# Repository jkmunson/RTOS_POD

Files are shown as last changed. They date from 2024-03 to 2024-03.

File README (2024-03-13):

BEGINNING OF NOTES BY WYATT:
3/10/2024

* TFT display guide: https://www.youtube.com/watch?v=3qnB5gsp8eE&t=2s
* SD card guide: https://01001000.xyz/2020-08-09-Tutorial-STM32CubeIDE-SD-card/
* All the SPI and GPIO pin assignments are made in the .ioc file.
* SCK, MISO, and MOSI are automaticly assigned by the SPI enabled in the .ioc
* ^ but CS, RESET, and DC need to be assigned manually.
* The ili9341.h file and main.h file will need to reflect the .ioc file pin assignments. 
* I used stack size = 512 for the display/SD thread. Testing lower values has caused a fault in the past.
* Will need to change the "startup file" from f4xxxx to whichever board we are using.
* None of the display's touch screen pins are used (i.e. T_IRQ1, T_DO, T_DIN, T_CS, T_CLK)

I was on an f4xxx board, but I used the following SPI/GPIOs for the SD/Display:
SD:
	SCK		->	PB10
	MISO	->	PC2
	MOSI	->	PC1
	CS		->	PC3
DISPLAY:
	SD0 (MISO)	->	n/a (specify master only transmit in .ioc)
	LED			->	+3.3V
	SCK			->	PA5
	SDI	(MOSI)	->	PA7
	DC			->	PB1
	RESET		->	PB0
	CS			->	PA4
	VCC			->  +5V
	
I uploaded my wyatt.c and wyatt.h code, but it doesn't look like main.c is configured for FreeRTOS to run.
Once it is, ADD THE FOLLOWING CODE AS ITS OWN THREAD:
  
*   HOW THE FSM WORKS:
	The display initializes by showing the names of the files on the SD card, and blinking to show which file is currently hovered over.
	Change boolean variables "sel_next" and "sel_prev" to highlight files other than the one currently highlighted.
	change boolean variable "readFile" to open the file that's currently hovered over and access its contents.
	change boolean variable "viewDirectory" to close the file you're reading and view the list of file names again.
	
	changing "readFile" while already reading a file does nothing.
	changing "viewDirectory" while already viewing the directory does nothing.
	
END OF NOTES BY WYATT.

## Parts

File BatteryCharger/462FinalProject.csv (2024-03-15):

Source: | /home/jkmunson/workspace/win24/RTOS_POD/BatteryCharger/462FinalProject.kicad_sch
Date: | Fri 15 Mar 2024 08:57:17 AM PDT
Tool: | Eeschema 7.0.10
Generator: | /app/share/kicad/plugins/bom_csv_grouped_by_value_with_fp.py
Component Count: | 46
Ref | Qnty | Value | Cmp name | Footprint | Description | Vendor | DNP
C1, C2, C3, C5, C6 | 5 | 10u | C_Small | Capacitor_SMD:C_0805_2012Metric_Pad1.18x1.45mm_HandSolder | Unpolarized capacitor, small symbol
C4 | 1 | .1u | C_Small | Capacitor_SMD:C_0805_2012Metric_Pad1.18x1.45mm_HandSolder | Unpolarized capacitor, small symbol
D1, D5, D6, D7 | 4 | MBR0530 | 1N5711 | Diode_SMD:D_SOD-123 | 70V 33mA Schottky diode, DO-35
IC1 | 1 | TPS562231DRLR | TPS562231DRLR | Library:SOTFL50P160X60-6N | 4.5-V to 17-V input, 2-A output, synchronous step-down converter
J2 | 1 | 3_Pin_Header_to_Battery | Conn_01x03_Pin | Connector_PinHeader_2.54mm:PinHeader_1x03_P2.54mm_Vertical | Generic connector, single row, 01x03, script generated
J3 | 1 | USB_B_Micro | USB_B_Micro | Library:USB_Micro-B_roundholes | USB Micro Type B connector
J4 | 1 | 3_Pin_Header_to_IPOD | Conn_01x03_Pin | Connector_PinHeader_2.54mm:PinHeader_1x03_P2.54mm_Vertical | Generic connector, single row, 01x03, script generated
J5 | 1 | Conn_01x04_Pin | Conn_01x04_Pin | Connector_PinHeader_2.54mm:PinHeader_1x04_P2.54mm_Vertical | Generic connector, single row, 01x04, script generated
L1 | 1 | SRR1205-500YL | SRR1205-500YL | Library:SRR1205500YL | Fixed Inductors 50uH 15% SMD 1205
L2 | 1 | 3.3u | L | Library:CC322522A-4R7K | Inductor
Q1, Q2 | 2 | MMFTN6001 | Q_NMOS_GSD | Package_TO_SOT_SMD:SOT-23 | N-MOSFET transistor, gate/source/drain
Q3, Q4, Q9 | 3 | SI2302 | Q_NMOS_GSD | Package_TO_SOT_SMD:SOT-23 | N-MOSFET transistor, gate/source/drain
Q6, Q7, Q8 | 3 | BSS84AK,215 | BSS84AK,215 | Library:SOT95P230X110-3N | BSS84AK,215 P-Channel MOSFET, 180 mA, 50 V, 3-Pin SOT-23 Nexperia
R1 | 1 | 100m | R | Resistor_SMD:R_0805_2012Metric | Resistor
R4, R10, R12 | 3 | 1k | R | Resistor_SMD:R_0805_2012Metric | Resistor
R5 | 1 | 45.3k | R | Library:CR0603-FX-4532ELF | Resistor
R9 | 1 | 100k | R | Resistor_SMD:R_0805_2012Metric | Resistor
RN1, RN2 | 2 | R_Pack04_Split_2 | R_Pack04_Split | Resistor_SMD:R_Array_Concave_4x0603 | 4 resistor network, parallel topology, split
TP1, TP2, TP3, TP4, TP5, TP6, TP7, TP8, TP9, TP10 | 10 | TestPoint | TestPoint | TestPoint:TestPoint_Loop_D2.50mm_Drill1.85mm | test point
U1 | 1 | MIC5504-3.3YM5 | MIC5504-3.3YM5 | Package_TO_SOT_SMD:SOT-23-5 | 300mA Low-dropout Voltage Regulator, Vout 3.3V, Vin up to 5.5V, SOT-23
U2 | 1 | STM32G030F6Px | STM32G030F6Px | Package_SO:TSSOP-20_4.4x6.5mm_P0.65mm | STMicroelectronics Arm Cortex-M0+ MCU, 32KB flash, 8KB RAM, 64 MHz, 2.0-3.6V, 17 GPIO, TSSOP20
U3 | 1 | ~ | MCP6489-E/SL | Package_SO:SOIC-14_3.9x8.7mm_P1.27mm

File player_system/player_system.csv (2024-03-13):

Component Count: |  | 190
Ref | Ordered? | Qnty | Value | Cmp name | Footprint | Description | Vendor | DNP
BIASTRIM1 | Y | 1 | 5k | R_Potentiometer_Trim | Potentiometer_THT:Potentiometer_ACP_CA9-H5_Horizontal | Trim-potentiometer
C1, C2 | Y | 2 | 10pf C0G 2% | C_Small | Capacitor_SMD:C_0805_2012Metric_Pad1.18x1.45mm_HandSolder | Unpolarized capacitor, small symbol
C3, C4, C5, C6 | Y | 4 | 100n | C_Small | Capacitor_SMD:C_0805_2012Metric_Pad1.18x1.45mm_HandSolder | Unpolarized capacitor, small symbol
C7, C8, C9, C10, C11, C12, C13, C14, C15, C16, C17, C18, C19, C20, C21, C22, C23, C24 | Y | 18 | 10uf | C_Small | Capacitor_SMD:C_0805_2012Metric_Pad1.18x1.45mm_HandSolder | Unpolarized capacitor, small symbol
C25 | Y | 1 | 10u | C_Small | Resistor_SMD:R_0805_2012Metric_Pad1.20x1.40mm_HandSolder | Unpolarized capacitor, small symbol
GAINTRIM1, GAINTRIM2 | Y | 2 | 10k | R_Potentiometer_Trim | Potentiometer_THT:Potentiometer_ACP_CA9-H5_Horizontal | Trim-potentiometer
J1 | Y | 1 | ~ | Conn_01x02_Pin | Connector_PinHeader_2.54mm:PinHeader_1x02_P2.54mm_Vertical | Generic connector, single row, 01x02, script generated
JTAG1 | Y | 1 | PGM | Conn_02x07_Odd_Even | Connector_PinHeader_1.27mm:PinHeader_2x07_P1.27mm_Vertical | Generic connector, double row, 02x07, odd/even pin numbering scheme (row 1 odd numbers, row 2 even numbers), script generated (kicad-library-utils/schlib/autogen/connector/)
NORFLASH1, NORFLASH2 | Y | 2 | ~ | IS25LP128F-JBLE-TR | Package_SO:SOP-8_5.28x5.23mm_P1.27mm
PWR_IN1 | Y | 1 | ~ | Conn_01x03_Pin_1 | Connector_PinHeader_2.54mm:PinHeader_1x03_P2.54mm_Vertical | Generic connector, single row, 01x03, script generated
Q1, Q2, Q3, Q4, Q5, Q6, Q7, Q8 | Y | 8 | SI2302 | Q_NMOS_GSD | Package_TO_SOT_SMD:SOT-23 | N-MOSFET transistor, gate/source/drain
R1, R2 | Y | 2 | 1k | R_Small | Resistor_SMD:R_0805_2012Metric_Pad1.20x1.40mm_HandSolder | Resistor, small symbol
RESET1 | Y | 1 | RESET | SW_Push | Button_Switch_SMD:SW_SPST_EVPBF | Push button switch, generic, two pins
RN1, RN2 | Y | 2 | 1M-1% | R_Pack04_Split | Resistor_SMD:R_Array_Convex_4x1206 | 4 resistor network, parallel topology, split
RN3, RN4, RN5, RN6, RN7 | Y | 5 | 10k | R_Pack04_Split | Resistor_SMD:R_Array_Concave_4x0603 | 4 resistor network, parallel topology, split
ROTARY1 | Y | 1 | ~ | RotaryEncoder_Switch | Rotary_Encoder:RotaryEncoder_Alps_EC11E-Switch_Vertical_H20mm_CircularMountingHoles | Rotary encoder, dual channel, incremental quadrate outputs, with switch
SD_DAT1, SD_DAT2 | Y | 2 | . | Conn_01x01_Socket | rtospod_footprints:tht_testpt | Generic connector, single row, 01x01, script generated
SDCARD1 | Y | 1 | ~ | Micro_SD_Card | rtospod_footprints:J_SD_Card-micro_socket_A | Micro SD Card Socket
SW1, SW2, SW3, SW4 | Y | 4 | ~ | SW_Push | Button_Switch_SMD:SW_SPST_EVPBF | Push button switch, generic, two pins
TFT1 | Y | 1 | ~ | PBC_ILI9341_2.8_TFT_SPI_240x320_V1.2 | rtospod_footprints:TFT_SPI_240X320
U1, U5 | Y | 2 | ~ | MCP6489-E/SL | Package_SO:SOIC-14_3.9x8.7mm_P1.27mm
U2 | Y | 1 | STM32G474VEHx | STM32G474VEHx | Package_BGA:TFBGA-100_8x8mm_Layout10x10_P0.8mm | STMicroelectronics Arm Cortex-M4 MCU, 512KB flash, 128KB RAM, 170 MHz, 1.71-3.6V, 86 GPIO, TFBGA100
U3 | Y | 1 | STM32G030F6Px | STM32G030F6Px | Package_SO:TSSOP-20_4.4x6.5mm_P0.65mm | STMicroelectronics Arm Cortex-M0+ MCU, 32KB flash, 8KB RAM, 64 MHz, 2.0-3.6V, 17 GPIO, TSSOP20
U4 | Y | 1 | LDI1117-05H | AP1117-15 | Package_TO_SOT_SMD:SOT-223-3_TabPin2 | 1A Low Dropout regulator, positive, 1.5V fixed output, SOT-223
VOLUME1 | Y | 1 | 5k | R_Potentiometer | rtospod_footprints:CIRCULAR_POT | Potentiometer
Y1 | Y | 1 | 16mhz 10ppm | Crystal_Small | Crystal:Crystal_SMD_2520-4Pin_2.5x2.0mm | Two pin crystal, small symbol
Reference |  | Qty | Value | Footprint | DNP | Manufacturer Part Number | Mouser Price/Stock
C1, C2, C3, C5, C6 | Y | 5 | 10u | Capacitor_SMD:C_0805_2012Metric_Pad1.18x1.45mm_HandSolder |  | CL21A106KOQNNNE | https://www.mouser.com/ProductDetail/Samsung-Electro-Mechanics/CL21A106KOQNNNE
C4 | Y | 1 | .1u | Capacitor_SMD:C_0805_2012Metric_Pad1.18x1.45mm_HandSolder |  | MSAST105SB5104KFNA01 | https://www.mouser.com/ProductDetail/TAIYO-YUDEN/MSAST105SB5104KFNA01
D1, D5, D6, D7 | Y | 4 | MBR0530 | Diode_SMD:D_SOD-123 |  | MBR0530 | https://www.mouser.com/ProductDetail/Micro-Commercial-Components-MCC/MBR0530-TP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
IC1 | Y | 1 | TPS562231DRLR | Library:SOTFL50P160X60-6N |  | TPS562231DRLR | https://www.mouser.co.uk/ProductDetail/Texas-Instruments/TPS562231DRLR?qs=l4Gc20tDgJK5KnXgCyg0Bw%3D%3D
J2 | Y | 1 | 3_Pin_Header_to_Battery | Connector_PinHeader_2.54mm:PinHeader_1x03_P2.54mm_Vertical
J3 | Y | 1 | USB_B_Micro | Library:USB_Micro-B_roundholes
J4 | Y | 1 | 3_Pin_Header_to_IPOD | Connector_PinHeader_2.54mm:PinHeader_1x03_P2.54mm_Vertical
J5 | Y | 1 | Conn_01x04_Pin | Connector_PinHeader_2.54mm:PinHeader_1x04_P2.54mm_Vertical
L1 | Y | 1 | SRR1205-500YL | Library:SRR1205500YL |  |  | https://www.mouser.co.uk/ProductDetail/Bourns/SRR1205-500YL?qs=iR9JlTGiDnVu0txHEBsynw%3D%3D
L2 | Y | 1 | 3.3u | Library:CC322522A-4R7K |  | CC322522A-4R7K | https://www.mouser.com/ProductDetail/Bourns/CC322522A-4R7K?qs=BJlw7L4Cy7%2Fy09%2BRq8LovQ%3D%3D
Q1, Q2 | Y | 2 | MMFTN6001 | Package_TO_SOT_SMD:SOT-23 |  | MMFTN6001 | https://www.mouser.com/ProductDetail/Diotec-Semiconductor/MMFTN6001?qs=Wj%2FVkw3K%252BMBEABncUaRa2w%3D%3D
Q3, Q4, Q9 | Y | 3 | SI2302 | Package_TO_SOT_SMD:SOT-23 |  | SI2302 | https://www.mouser.com/ProductDetail/Micro-Commercial-Components-MCC/SI2302?qs=6W4OQKoqJ0s%2FjuQxID9btg%3D%3D
Q6, Q7, Q8 | Y | 3 | BSS84AK,215 | Library:SOT95P230X110-3N |  | BSS84AK,215 | https://www.mouser.co.uk/ProductDetail/Nexperia/BSS84AK215?qs=A1cBxND5mHJndJgHJTE1yg%3D%3D
R1 | Y | 1 | 100m | Resistor_SMD:R_0805_2012Metric |  | 73L3R10J | https://www.mouser.com/ProductDetail/CTS-Electronic-Components/73L3R10J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
R4, R10, R12 | Y | 3 | 1k | Resistor_SMD:R_0805_2012Metric |  | CR0805-JW-102ELF | https://www.mouser.com/ProductDetail/Bourns/CR0805-JW-102ELF?qs=sGAEpiMZZMtlubZbdhIBIPJRFm2x4gVbKRFwRkY2vaI%3D
R5 | Y | 1 | 45.3k | Library:CR0603-FX-4532ELF |  | RC0805FR-0745K3L | https://www.mouser.com/ProductDetail/YAGEO/RC0805FR-0745K3L
R9 | Y | 1 | 100k | Resistor_SMD:R_0805_2012Metric |  | RC0805JR-10100KL | https://www.mouser.com/ProductDetail/YAGEO/RC0805JR-10100KL
RN1, RN2 | Y | 2 | R_Pack04_Split_2 | Resistor_SMD:R_Array_Concave_4x0603
TP1, TP2, TP3, TP4, TP5, TP6, TP7, TP8, TP9, TP10 |  | 10 | TestPoint | TestPoint:TestPoint_Loop_D2.50mm_Drill1.85mm
U1 | Y | 1 | MIC5504-3.3YM5 | Package_TO_SOT_SMD:SOT-23-5
U2 | Y | 1 | STM32G030F6Px | Package_SO:TSSOP-20_4.4x6.5mm_P0.65mm
U3 |  | 1 | ~ | Package_SO:SOIC-14_3.9x8.7mm_P1.27mm

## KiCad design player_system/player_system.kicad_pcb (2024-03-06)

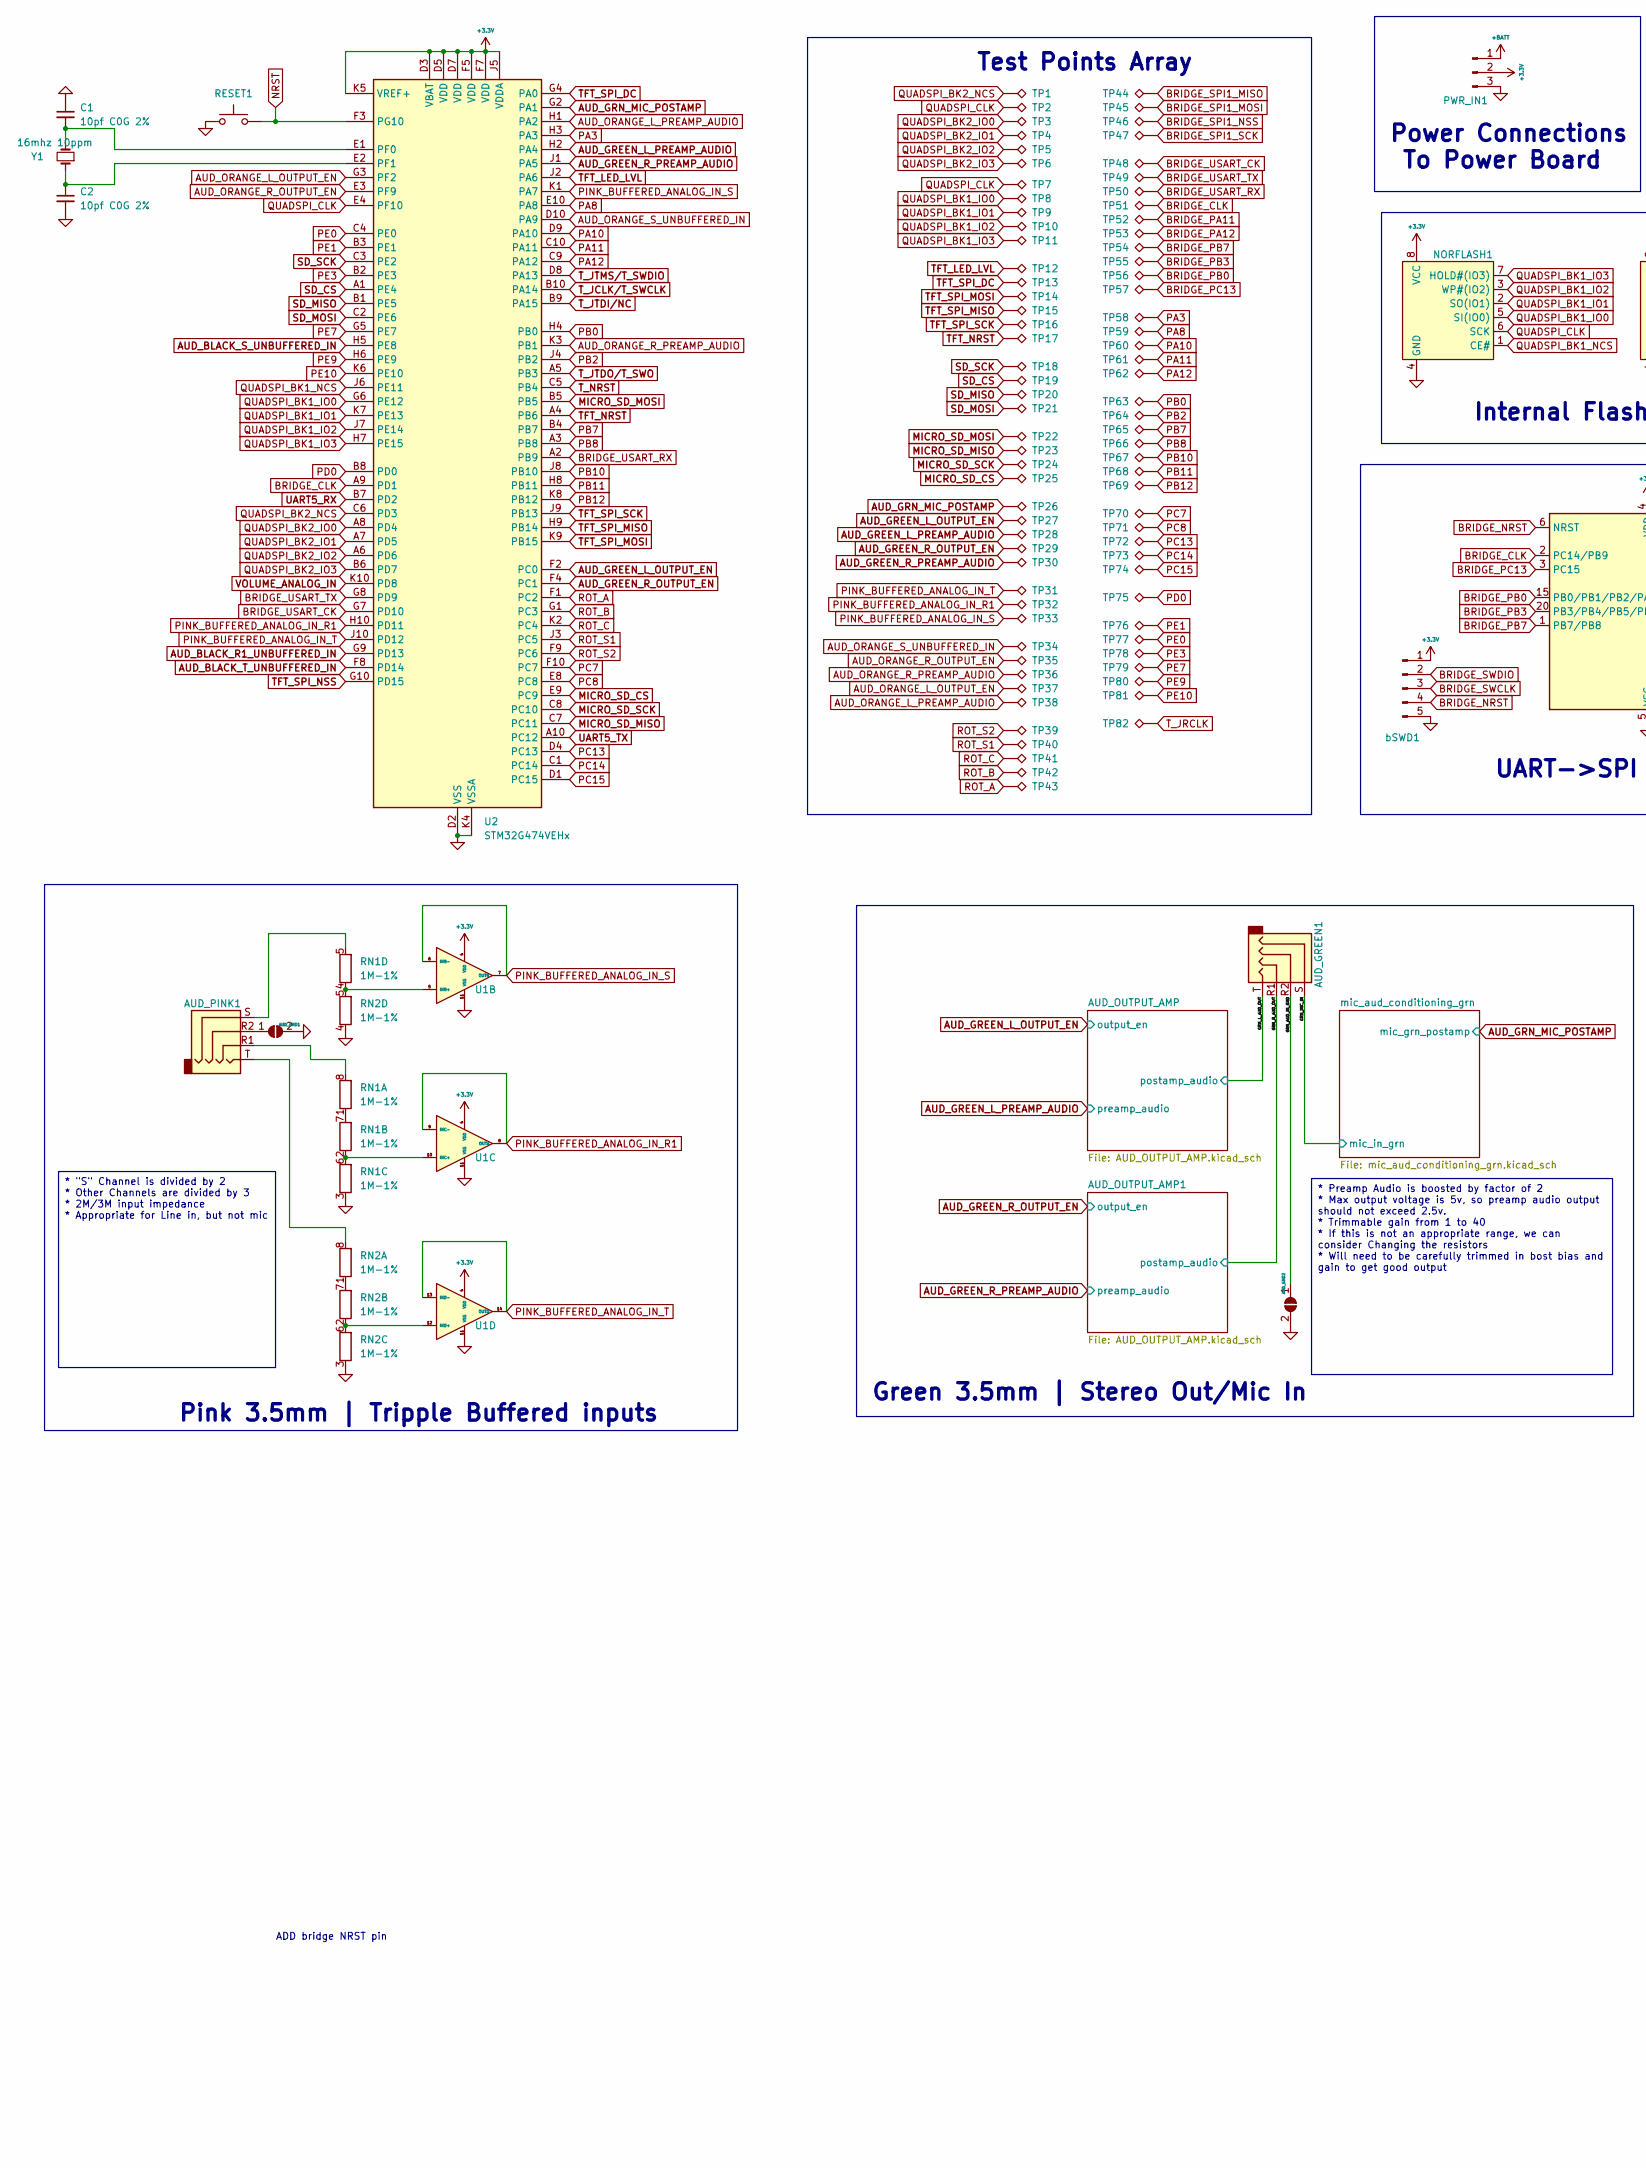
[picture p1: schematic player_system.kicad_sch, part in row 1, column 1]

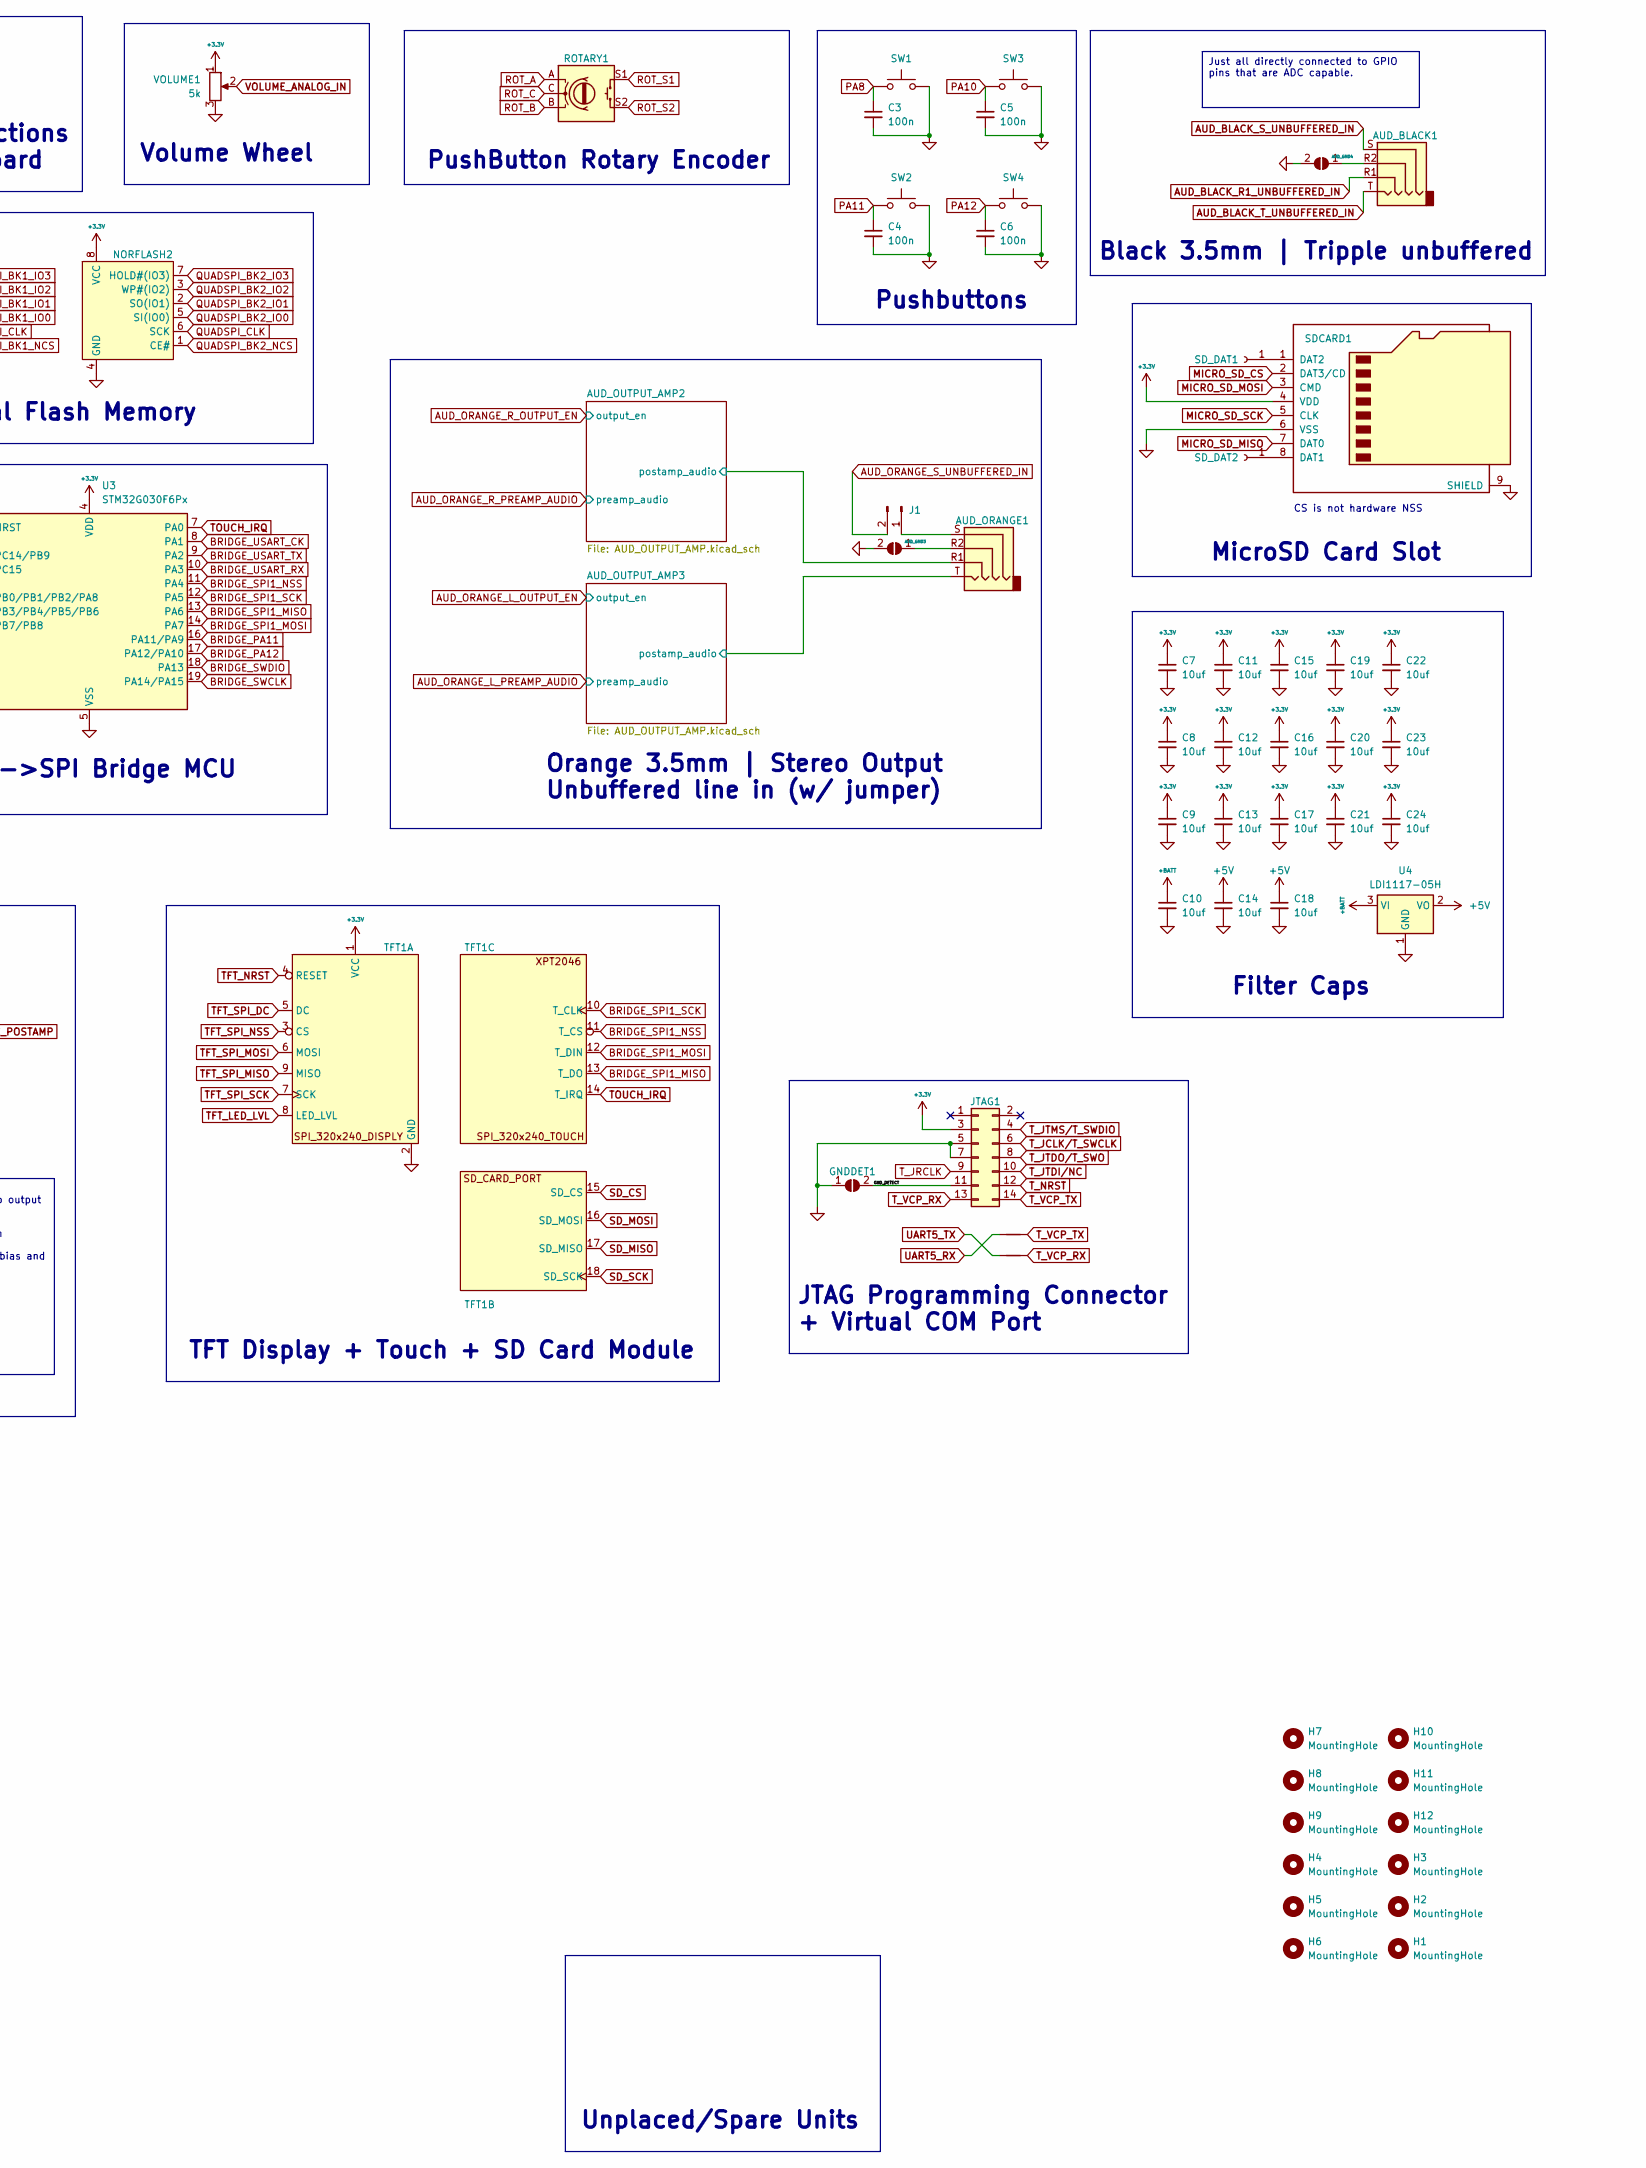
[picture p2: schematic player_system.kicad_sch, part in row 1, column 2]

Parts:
AUD_BLACK1: TRRS_JACK_3.5mm
AUD_GND1, AUD_GND2, AUD_GND3, AUD_GND4: SolderJumper_2_Open; SolderJumper-2_P1.3mm_Open_RoundedPad1.0x1.5mm
AUD_GREEN1: TRRS_JACK_3.5mm
AUD_ORANGE1: TRRS_JACK_3.5mm
AUD_PINK1: TRRS_JACK_3.5mm
C1, C2: 10pf C0G 2%; C_0805_2012Metric_Pad1.18x1.45mm_HandSolder
C3, C4, C5, C6: 100n; C_0805_2012Metric_Pad1.18x1.45mm_HandSolder
C7, C8, C9, C10, C11, C12, C13, C14, C15, C16, C17, C18, C19, C20, C21, C22, C23, C24: 10uf; C_0805_2012Metric_Pad1.18x1.45mm_HandSolder
GNDDET1: SolderJumper_2_Open; SolderJumper-2_P1.3mm_Open_RoundedPad1.0x1.5mm
H1, H2, H3, H4, H5, H6, H7, H8, H9, H10, H11, H12: MountingHole; MountingHole_2.2mm_M2
J1: PinHeader_1x02_P2.54mm_Vertical
JTAG1: PGM; PinHeader_2x07_P1.27mm_Vertical
NORFLASH1, NORFLASH2: SOP-8_5.28x5.23mm_P1.27mm
NT2, NT3: NetTie_2; NetTie-2_SMD_Pad0.5mm
PWR_IN1: PinHeader_1x03_P2.54mm_Vertical
RESET1: RESET; SW_SPST_EVPBF
RN1, RN2: 1M-1%; R_Array_Convex_4x1206
ROTARY1: RotaryEncoder_Alps_EC11E-Switch_Vertical_H20mm_CircularMoun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
SDCARD1: J_SD_Card-micro_socket_A
SD_DAT1, SD_DAT2: .; tht_testpt
SW1, SW2, SW3, SW4: SW_SPST_EVPBF
TFT1: TFT_SPI_240X320
TP1, TP2, TP3, TP4, TP5, TP6, TP7, TP8, TP9, TP10, TP11, TP12, TP13, TP14, TP15, TP16, TP17, TP18, TP19, TP20, TP21, TP22, TP23, TP24, TP25, TP26, TP27, TP28, TP29, TP30, TP31, TP32, TP33, TP34, TP35, TP36, TP37, TP38, TP39, TP40, TP41, TP42, TP43, TP44, TP45, TP46, TP47, TP48, TP49, TP50, TP51, TP52, TP53, TP54, TP55, TP56, TP57, TP58, TP59, TP60, TP61, TP62, TP63, TP64, TP65, TP66, TP67, TP68, TP69, TP70, TP71, TP72, TP73, TP74, TP75, TP76, TP77, TP78, TP79, TP80, TP81, TP82: tht_testpt
U1: SOIC-14_3.9x8.7mm_P1.27mm
U2: STM32G474VEHx; TFBGA-100_8x8mm_Layout10x10_P0.8mm
U3: STM32G030F6Px; TSSOP-20_4.4x6.5mm_P0.65mm
U4: LDI1117-05H; SOT-223-3_TabPin2
VOLUME1: 5k; CIRCULAR_POT
Y1: 16mhz 10ppm; Crystal_SMD_2520-4Pin_2.5x2.0mm
bSWD1: BRIDGE_SWD; PinHeader_1x05_P2.54mm_Vertical

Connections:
+3.3V: C7.1, C8.1, C9.1, C11.1, C12.1, C13.1, C15.1, C16.1, C17.1, C19.1, C20.1, C21.1, C22.1, C23.1, C24.1, JTAG1.3, NORFLASH1.8 (VCC), NORFLASH2.8 (VCC), PWR_IN1.2, SDCARD1.4 (VDD), TFT1.1 (VCC), U1.4 (VDD), U2.D3 (VBAT), U2.D5 (VDD), U2.D7 (VDD), U2.F5 (VDD), U2.F7 (VDD), U2.J5 (VDDA), U2.K5 (VREF+), U3.4 (VDD), VOLUME1.1, bSWD1.1; also elsewhere on the board
+5V: C14.1, C18.1, U4.2 (VO); also elsewhere on the board
+BATT: C10.1, PWR_IN1.1, U4.3 (VI); also elsewhere on the board
/AUD_OUTPUT_AMP2/postamp_audio: AUD_ORANGE1.R1; also elsewhere on the board
/AUD_OUTPUT_AMP3/postamp_audio: AUD_ORANGE1.T; also elsewhere on the board
/GND_DETECT: GNDDET1.2 (B), JTAG1.11
/GRN_AUD_IN_GND: AUD_GND2.1 (A), AUD_GREEN1.R2
/GRN_L_AUD_OUT: AUD_GREEN1.T; also elsewhere on the board
/GRN_MIC_IN: AUD_GREEN1.S; also elsewhere on the board
/GRN_R_AUD_OUT: AUD_GREEN1.R1; also elsewhere on the board
AUD_BLACK_R1_UNBUFFERED_IN: AUD_BLACK1.R1, U2.G9 (PD13)
AUD_BLACK_S_UNBUFFERED_IN: AUD_BLACK1.S, U2.H5 (PE8)
AUD_BLACK_T_UNBUFFERED_IN: AUD_BLACK1.T, U2.F8 (PD14)
AUD_GREEN_L_OUTPUT_EN: TP27.1, U2.F2 (PC0); also elsewhere on the board
AUD_GREEN_L_PREAMP_AUDIO: TP28.1, U2.H2 (PA4); also elsewhere on the board
AUD_GREEN_R_OUTPUT_EN: TP29.1, U2.F4 (PC1); also elsewhere on the board
AUD_GREEN_R_PREAMP_AUDIO: TP30.1, U2.J1 (PA5); also elsewhere on the board
AUD_GRN_MIC_POSTAMP: TP26.1, U2.G2 (PA1); also elsewhere on the board
AUD_ORANGE_L_OUTPUT_EN: TP37.1, U2.G3 (PF2); also elsewhere on the board
AUD_ORANGE_L_PREAMP_AUDIO: TP38.1, U2.H1 (PA2); also elsewhere on the board
AUD_ORANGE_R_OUTPUT_EN: TP35.1, U2.E3 (PF9); also elsewhere on the board
AUD_ORANGE_R_PREAMP_AUDIO: TP36.1, U2.K3 (PB1); also elsewhere on the board
AUD_ORANGE_S_UNBUFFERED_IN: J1.2, TP34.1, U2.D10 (PA9)
BRIDGE_CLK: TP51.1, U2.A9 (PD1), U3.2 (PC14/PB9)
BRIDGE_NRST: U3.6 (NRST), bSWD1.4
BRIDGE_PA11: TP52.1, U3.16 (PA11/PA9)
BRIDGE_PA12: TP53.1, U3.17 (PA12/PA10)
BRIDGE_PB0: TP56.1, U3.15 (PB0/PB1/PB2/PA8)
BRIDGE_PB3: TP55.1, U3.20 (PB3/PB4/PB5/PB6)
BRIDGE_PB7: TP54.1, U3.1 (PB7/PB8)
BRIDGE_PC13: TP57.1, U3.3 (PC15)
BRIDGE_SPI1_MISO: TFT1.13 (T_DO), TP44.1, U3.13 (PA6)
BRIDGE_SPI1_MOSI: TFT1.12 (T_DIN), TP45.1, U3.14 (PA7)
BRIDGE_SPI1_NSS: TFT1.11 (T_CS), TP46.1, U3.11 (PA4)
BRIDGE_SPI1_SCK: TFT1.10 (T_CLK), TP47.1, U3.12 (PA5)
BRIDGE_SWCLK: U3.19 (PA14/PA15), bSWD1.3
BRIDGE_SWDIO: U3.18 (PA13), bSWD1.2
BRIDGE_USART_CK: TP48.1, U2.G7 (PD10), U3.8 (PA1)
BRIDGE_USART_RX: TP50.1, U2.A2 (PB9), U3.10 (PA3)
BRIDGE_USART_TX: TP49.1, U2.G8 (PD9), U3.9 (PA2)
GND: AUD_GND1.2 (B), AUD_GND2.2 (B), AUD_GND3.2 (B), AUD_GND4.2 (B), C1.1, C2.2, C3.2, C4.2, C5.2, C6.2, C7.2, C8.2, C9.2, C10.2, C11.2, C12.2, C13.2, C14.2, C15.2, C16.2, C17.2, C18.2, C19.2, C20.2, C21.2, C22.2, C23.2, C24.2, GNDDET1.1 (A), JTAG1.5, JTAG1.7, NORFLASH1.4 (GND), NORFLASH2.4 (GND), PWR_IN1.3, RESET1.1, RN1.3 (R3.1), RN2.3 (R3.1), RN2.4 (R4.1), SDCARD1.6 (VSS), SDCARD1.9 (SHIELD), SW1.2, SW2.2, SW3.2, SW4.2, TFT1.2 (GND), U1.11 (VSS), U2.D2 (VSS), U2.D6 (VSS), U2.E5 (VSS), U2.E6 (VSS), U2.E7 (VSS), U2.F6 (VSS), U2.K4 (VSSA), U3.5 (VSS), U4.1 (GND), VOLUME1.3, bSWD1.5; also elsewhere on the board
MICRO_SD_CS: SDCARD1.2 (DAT3/CD), TP25.1, U2.E9 (PC9)
MICRO_SD_MISO: SDCARD1.7 (DAT0), TP23.1, U2.C7 (PC11)
MICRO_SD_MOSI: SDCARD1.3 (CMD), TP22.1, U2.B5
MICRO_SD_SCK: SDCARD1.5 (CLK), TP24.1, U2.C8 (PC10)
NRST: RESET1.2, U2.F3 (PG10)
unnamed: AUD_GND1.1 (A), AUD_PINK1.R2
unnamed: AUD_GND3.1 (A), AUD_ORANGE1.R2
unnamed: AUD_BLACK1.R2, AUD_GND4.1 (A)
unnamed: AUD_ORANGE1.S, J1.1
unnamed: RN1.1 (R1.1), RN1.7 (R2.2)
unnamed: AUD_PINK1.R1, RN1.8 (R1.2)
unnamed: RN1.2 (R2.1), RN1.6 (R3.2), U1.10 (INC+)
unnamed: RN1.4 (R4.1), RN2.5 (R4.2), U1.5 (INB+)
unnamed: AUD_PINK1.S, RN1.5 (R4.2)
unnamed: RN2.1 (R1.1), RN2.7 (R2.2)
unnamed: AUD_PINK1.T, RN2.8 (R1.2)
unnamed: RN2.2 (R2.1), RN2.6 (R3.2), U1.12 (IND+)
unnamed: SDCARD1.8 (DAT1), SD_DAT2.1
unnamed: SDCARD1.1 (DAT2), SD_DAT1.1
unnamed: C1.2, U2.E1 (PF0), Y1.2, Y1.3 (2)
unnamed: C2.1, U2.E2 (PF1), Y1.1, Y1.4 (1)
PA3: TP58.1, U2.H3 (PA3)
PA8: C3.1, SW1.1, TP59.1, U2.E10 (PA8)
PA10: C5.1, SW3.1, TP60.1, U2.D9 (PA10)
PA11: C4.1, SW2.1, TP61.1, U2.C10 (PA11)
PA12: C6.1, SW4.1, TP62.1, U2.C9 (PA12)
PB0: TP63.1, U2.H4 (PB0)
PB2: TP64.1, U2.J4 (PB2)
PB7: TP65.1, U2.B4 (PB7)
PB8: TP66.1, U2.A3 (PB8)
PB10: TP67.1, U2.J8 (PB10)
PB11: TP68.1, U2.H8 (PB11)
PB12: TP69.1, U2.K8 (PB12)
PC7: TP70.1, U2.F10 (PC7)
PC8: TP71.1, U2.E8 (PC8)
PC13: TP72.1, U2.D4 (PC13)
PC14: TP73.1, U2.C1 (PC14)
PC15: TP74.1, U2.D1 (PC15)
PD0: TP75.1, U2.B8 (PD0)
PE0: TP77.1, U2.C4 (PE0)
PE1: TP76.1, U2.B3 (PE1)
PE3: TP78.1, U2.B2 (PE3)
PE7: TP79.1, U2.G5 (PE7)
PE9: TP80.1, U2.H6 (PE9)
PE10: TP81.1, U2.K6 (PE10)
PINK_BUFFERED_ANALOG_IN_R1: TP32.1, U1.8 (OUTA), U1.9 (INC-), U2.H10 (PD11)
PINK_BUFFERED_ANALOG_IN_S: TP33.1, U1.6 (INB-), U1.7 (OUTB), U2.K1 (PA7)
PINK_BUFFERED_ANALOG_IN_T: TP31.1, U1.13 (IND-), U1.14 (OUTD), U2.J10 (PD12)
QUADSPI_BK1_IO0: NORFLASH1.5 (SI(IO0)), TP8.1, U2.G6 (PE12)
QUADSPI_BK1_IO1: NORFLASH1.2 (SO(IO1)), TP9.1, U2.K7 (PE13)
QUADSPI_BK1_IO2: NORFLASH1.3 (WP#(IO2)), TP10.1, U2.J7 (PE14)
QUADSPI_BK1_IO3: NORFLASH1.7 (HOLD#(IO3)), TP11.1, U2.H7 (PE15)
QUADSPI_BK1_NCS: NORFLASH1.1 (CE#), U2.J6 (PE11)
QUADSPI_BK2_IO0: NORFLASH2.5 (SI(IO0)), TP3.1, U2.A8 (PD4)
QUADSPI_BK2_IO1: NORFLASH2.2 (SO(IO1)), TP4.1, U2.A7 (PD5)
QUADSPI_BK2_IO2: NORFLASH2.3 (WP#(IO2)), TP5.1, U2.A6 (PD6)
QUADSPI_BK2_IO3: NORFLASH2.7 (HOLD#(IO3)), TP6.1, U2.B6 (PD7)
QUADSPI_BK2_NCS: NORFLASH2.1 (CE#), TP1.1, U2.C6 (PD3)
QUADSPI_CLK: NORFLASH1.6 (SCK), NORFLASH2.6 (SCK), TP2.1, TP7.1, U2.E4 (PF10)
ROT_A: ROTARY1.A, TP43.1, U2.F1 (PC2)
ROT_B: ROTARY1.B, TP42.1, U2.G1 (PC3)
ROT_C: ROTARY1.C, TP41.1, U2.K2 (PC4)
ROT_S1: ROTARY1.S1, TP40.1, U2.J3 (PC5)
ROT_S2: ROTARY1.S2, TP39.1, U2.F9 (PC6)
SD_CS: TFT1.15 (SD_CS), TP19.1, U2.A1 (PE4)
SD_MISO: TFT1.17 (SD_MISO), TP20.1, U2.B1 (PE5)
SD_MOSI: TFT1.16 (SD_MOSI), TP21.1, U2.C2 (PE6)
SD_SCK: TFT1.18 (SD_SCK), TP18.1, U2.C3 (PE2)
TFT_LED_LVL: TFT1.8 (LED_LVL), TP12.1, U2.J2 (PA6)
TFT_NRST: TFT1.4 (RESET), TP17.1, U2.A4 (PB6)
TFT_SPI_DC: TFT1.5 (DC), TP13.1, U2.G4 (PA0)
TFT_SPI_MISO: TFT1.9 (MISO), TP15.1, U2.H9 (PB14)
TFT_SPI_MOSI: TFT1.6 (MOSI), TP14.1, U2.K9 (PB15)
TFT_SPI_NSS: TFT1.3 (CS), U2.G10 (PD15)
TFT_SPI_SCK: TFT1.7 (SCK), TP16.1, U2.J9 (PB13)
TOUCH_IRQ: TFT1.14 (T_IRQ), U3.7 (PA0)
T_JCLK/T_SWCLK: JTAG1.6, U2.B10 (PA14)
T_JRCLK: JTAG1.9, TP82.1
T_JTDI/NC: JTAG1.10, U2.B9 (PA15)
T_JTDO/T_SWO: JTAG1.8, U2.A5 (PB3)
T_JTMS/T_SWDIO: JTAG1.4, U2.D8 (PA13)
T_NRST: JTAG1.12, U2.C5 (PB4)
T_VCP_RX: JTAG1.13, NT3.2
T_VCP_TX: JTAG1.14, NT2.2
UART5_RX: NT2.1, U2.B7 (PD2)
UART5_TX: NT3.1, U2.A10 (PC12)
VOLUME_ANALOG_IN: U2.K10 (PD8), VOLUME1.2

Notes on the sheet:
* "S" Channel is divided by 2 * Other Channels are divided by 3 * 2M/3M input impedance * Appropriate for Line in, but not mic
* Preamp Audio is boosted by factor of 2 * Max output voltage is 5v, so preamp audio output should not exceed 2.5v. * Trimmable gain from 1 to 40 * If this is not an appropriate range, we can consider Changing the resistors * Will need to be carefully trimmed in bost bias and gain to get good output
Just all directly connected to GPIO pins that are ADC capable.
MicroSD Card Slot
JTAG Programming Connector + Virtual COM Port
CS is not hardware NSS
Unplaced/Spare Units
Power Connections To Power Board
Orange 3.5mm | Stereo Output Unbuffered line in (w/ jumper)
Black 3.5mm | Tripple unbuffered
TFT Display + Touch + SD Card Module
ADD bridge NRST pin
Volume Wheel
Pink 3.5mm | Tripple Buffered inputs
Test Points Array
Pushbuttons
Filter Caps
Green 3.5mm | Stereo Out/Mic In
Internal Flash Memory
UART->SPI Bridge MCU
PushButton Rotary Encoder

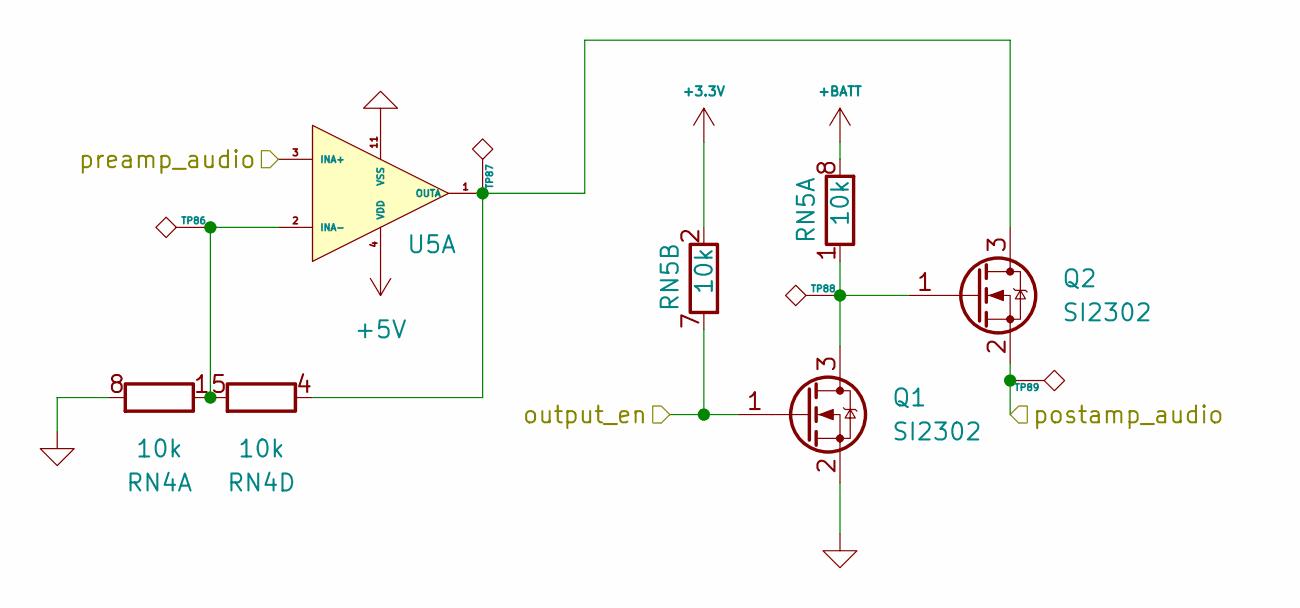
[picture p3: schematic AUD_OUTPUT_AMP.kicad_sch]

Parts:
Q1, Q2: SI2302; SOT-23
RN4, RN5: 10k; R_Array_Concave_4x0603
TP86, TP87, TP88, TP89: tht_testpt
U5: SOIC-14_3.9x8.7mm_P1.27mm

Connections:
+3.3V: RN5.2 (R2.1), RN5.3 (R3.1); also elsewhere on the board
+5V: U5.4 (VDD); also elsewhere on the board
+BATT: RN5.5 (R4.2), RN5.8 (R1.2); also elsewhere on the board
/GRN_L_AUD_OUT: Q2.2 (S), TP89.1; also elsewhere on the board
AUD_GREEN_L_OUTPUT_EN: Q1.1 (G), RN5.7 (R2.2); also elsewhere on the board
AUD_GREEN_L_PREAMP_AUDIO: U5.3 (INA+); also elsewhere on the board
AUD_GREEN_R_OUTPUT_EN: RN5.6 (R3.2); also elsewhere on the board
AUD_GREEN_R_PREAMP_AUDIO: U5.5 (INB+); also elsewhere on the board
AUD_ORANGE_L_PREAMP_AUDIO: U5.10 (INC+); also elsewhere on the board
AUD_ORANGE_R_PREAMP_AUDIO: U5.12 (IND+); also elsewhere on the board
GND: Q1.2 (S), RN4.6 (R3.2), RN4.8 (R1.2), U5.11 (VSS); also elsewhere on the board
unnamed: Q1.3 (D), Q2.1 (G), RN5.1 (R1.1), TP88.1
unnamed: Q2.3 (D), RN4.4 (R4.1), TP87.1, U5.1 (OUTA)
unnamed 53: RN5.4 (R4.1); also elsewhere on the board
unnamed 54: RN4.2 (R2.1), U5.7 (OUTB); also elsewhere on the board
unnamed 56: U5.14 (OUTD); also elsewhere on the board
unnamed 58: U5.8 (OUTA); also elsewhere on the board
unnamed: RN4.1 (R1.1), RN4.5 (R4.2), TP86.1, U5.2 (INA-)
unnamed 69: RN4.3 (R3.1), RN4.7 (R2.2), U5.6 (INB-); also elsewhere on the board
unnamed 70: U5.13 (IND-); also elsewhere on the board
unnamed 71: U5.9 (INC-); also elsewhere on the board

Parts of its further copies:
Q3, Q4, Q5, Q6, Q7, Q8: SI2302; SOT-23
RN6, RN7: 10k; R_Array_Concave_4x0603
TP90, TP91, TP92, TP93, TP94, TP95, TP96, TP97, TP98, TP99, TP100, TP101: tht_testpt

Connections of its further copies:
+3.3V: RN6.1 (R1.1), RN6.4 (R4.1); also elsewhere on the board
+BATT: RN7.5 (R4.2), RN7.8 (R1.2); also elsewhere on the board
/AUD_OUTPUT_AMP2/postamp_audio: Q6.2 (S), TP97.1; also elsewhere on the board
/AUD_OUTPUT_AMP3/postamp_audio: Q8.2 (S), TP101.1; also elsewhere on the board
/GRN_R_AUD_OUT: Q4.2 (S), TP93.1; also elsewhere on the board
AUD_GREEN_R_OUTPUT_EN: Q3.1 (G); also elsewhere on the board
AUD_ORANGE_L_OUTPUT_EN: Q7.1 (G), RN6.8 (R1.2); also elsewhere on the board
AUD_ORANGE_R_OUTPUT_EN: Q5.1 (G), RN6.5 (R4.2); also elsewhere on the board
GND: Q3.2 (S), Q5.2 (S), Q7.2 (S), RN6.6 (R3.2), RN7.6 (R3.2); also elsewhere on the board
unnamed 53: Q3.3 (D), Q4.1 (G), TP92.1; also elsewhere on the board
unnamed 54: Q4.3 (D), TP91.1; also elsewhere on the board
unnamed: Q5.3 (D), Q6.1 (G), RN7.1 (R1.1), TP96.1
unnamed 56: Q6.3 (D), RN6.2 (R2.1), TP95.1; also elsewhere on the board
unnamed: Q7.3 (D), Q8.1 (G), RN7.4 (R4.1), TP100.1
unnamed 58: Q8.3 (D), RN7.2 (R2.1), TP99.1; also elsewhere on the board
unnamed 69: TP90.1; also elsewhere on the board
unnamed 70: RN6.3 (R3.1), RN6.7 (R2.2), TP94.1; also elsewhere on the board
unnamed 71: RN7.3 (R3.1), RN7.7 (R2.2), TP98.1; also elsewhere on the board

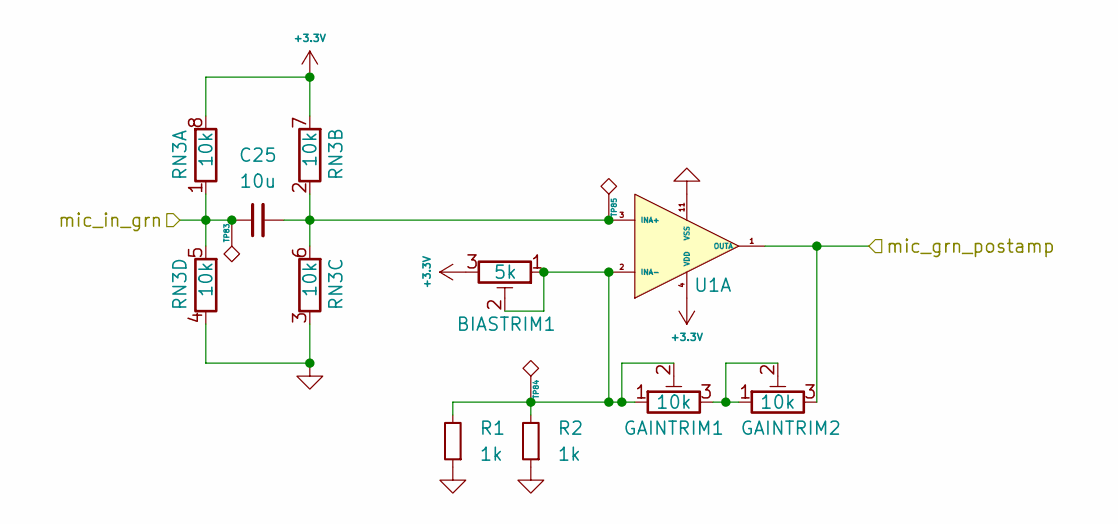
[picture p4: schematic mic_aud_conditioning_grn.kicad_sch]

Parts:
BIASTRIM1: 5k; Potentiometer_ACP_CA9-H5_Horizontal
C25: 10u; R_0805_2012Metric_Pad1.20x1.40mm_HandSolder
GAINTRIM1, GAINTRIM2: 10k; Potentiometer_ACP_CA9-H5_Horizontal
R1, R2: 1k; R_0805_2012Metric_Pad1.20x1.40mm_HandSolder
RN3: 10k; R_Array_Concave_4x0603
TP83, TP84, TP85: tht_testpt
U1: SOIC-14_3.9x8.7mm_P1.27mm

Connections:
+3.3V: BIASTRIM1.3, RN3.7 (R2.2), RN3.8 (R1.2), U1.4 (VDD); also elsewhere on the board
/GRN_MIC_IN: C25.1, RN3.1 (R1.1), RN3.5 (R4.2), TP83.1; also elsewhere on the board
AUD_GRN_MIC_POSTAMP: GAINTRIM2.3, U1.1 (OUTA); also elsewhere on the board
GND: R1.1, R2.1, RN3.3 (R3.1), RN3.4 (R4.1), U1.11 (VSS); also elsewhere on the board
unnamed: GAINTRIM1.3, GAINTRIM2.1, GAINTRIM2.2
unnamed: C25.2, RN3.2 (R2.1), RN3.6 (R3.2), TP85.1, U1.3 (INA+)
unnamed: BIASTRIM1.1, BIASTRIM1.2, GAINTRIM1.1, GAINTRIM1.2, R1.2, R2.2, TP84.1, U1.2 (INA-)

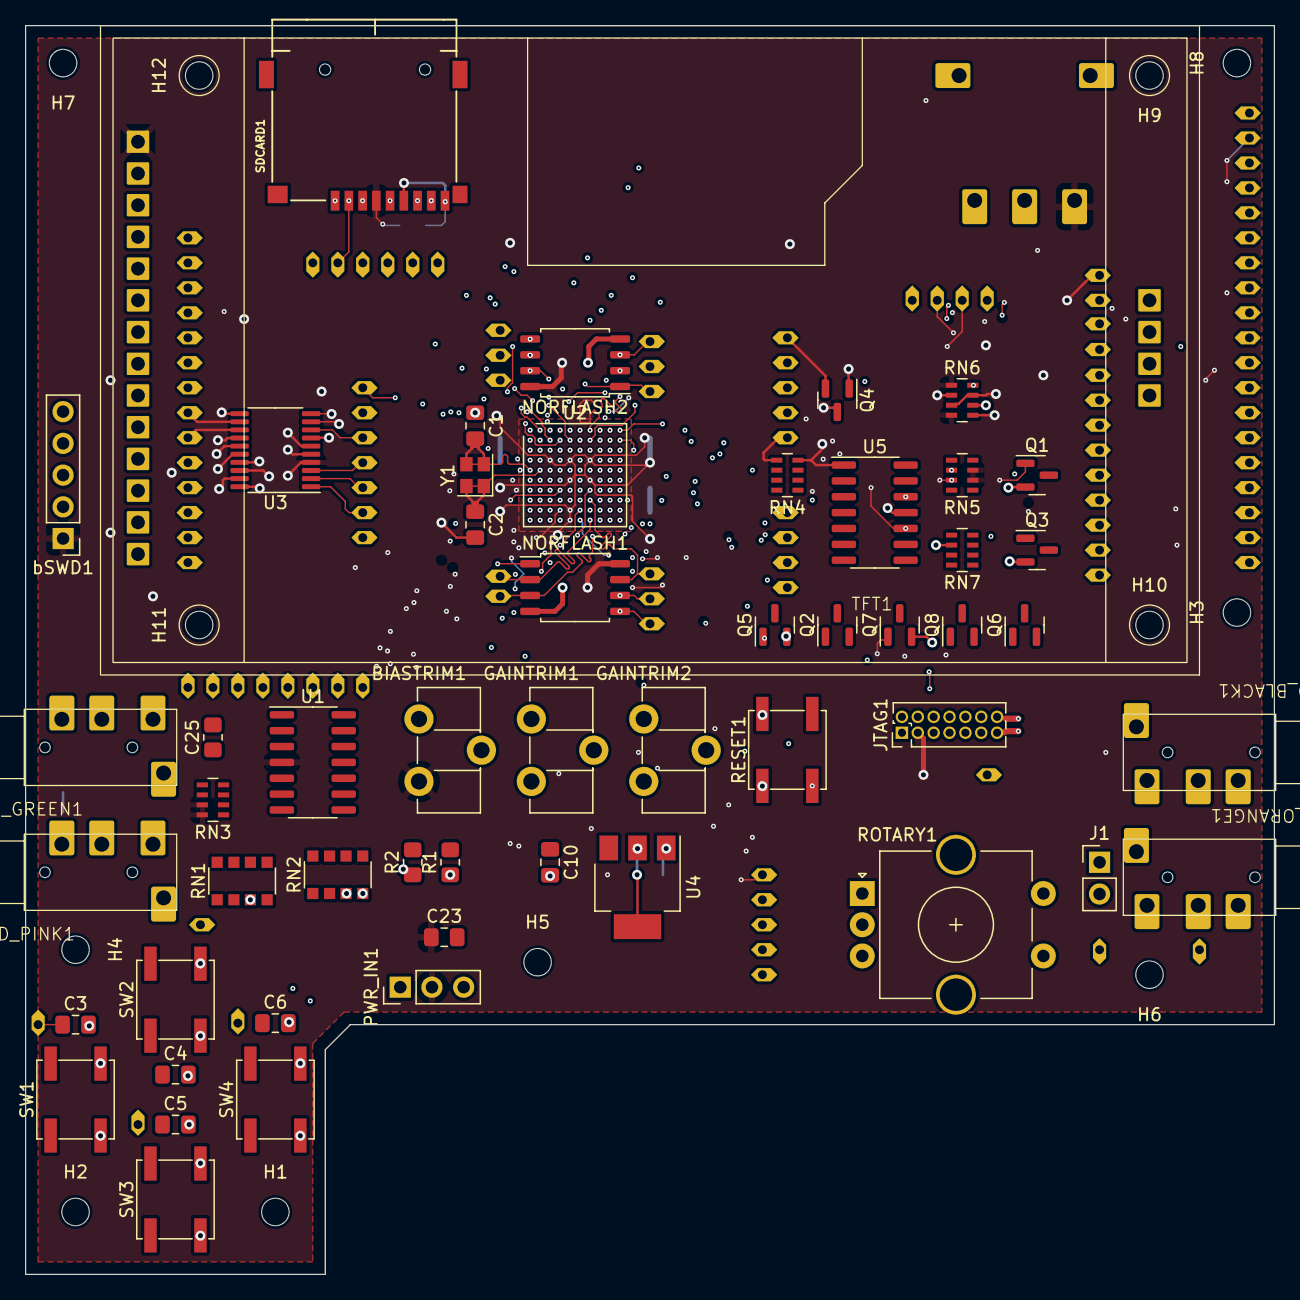
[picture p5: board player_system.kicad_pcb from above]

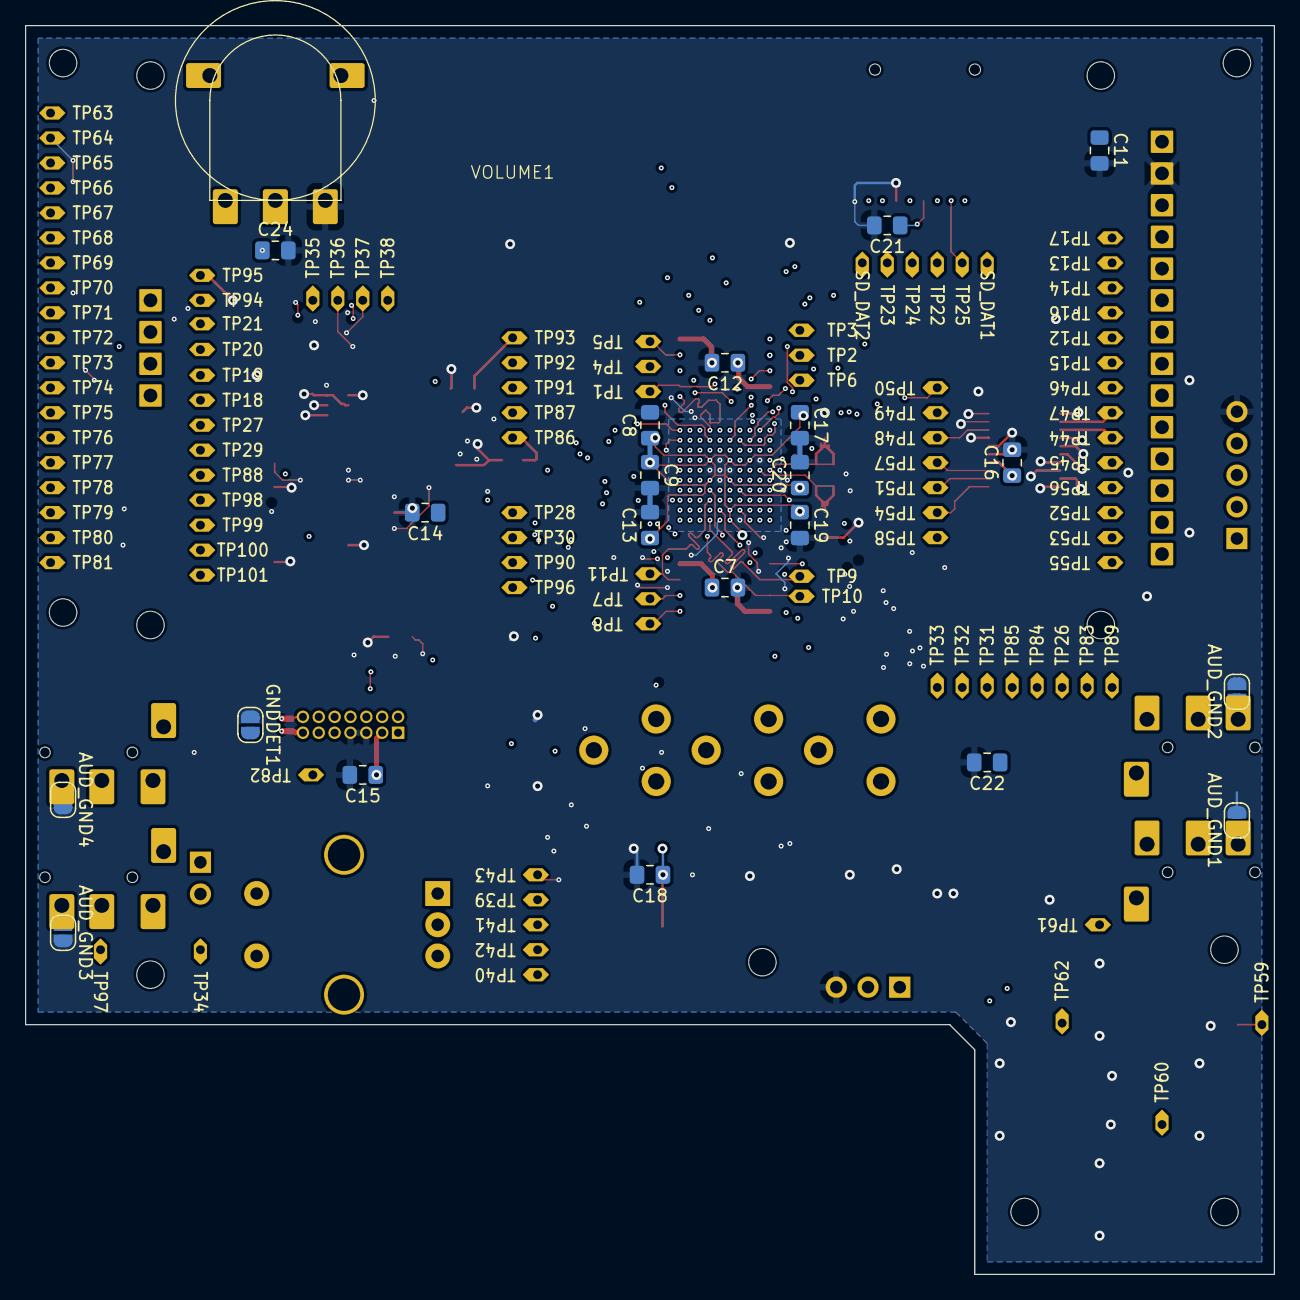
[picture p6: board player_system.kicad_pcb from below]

Board: 4 copper layers, 100.0 x 100.0 mm, 192 parts (125 on the bottom side), 143 nets.

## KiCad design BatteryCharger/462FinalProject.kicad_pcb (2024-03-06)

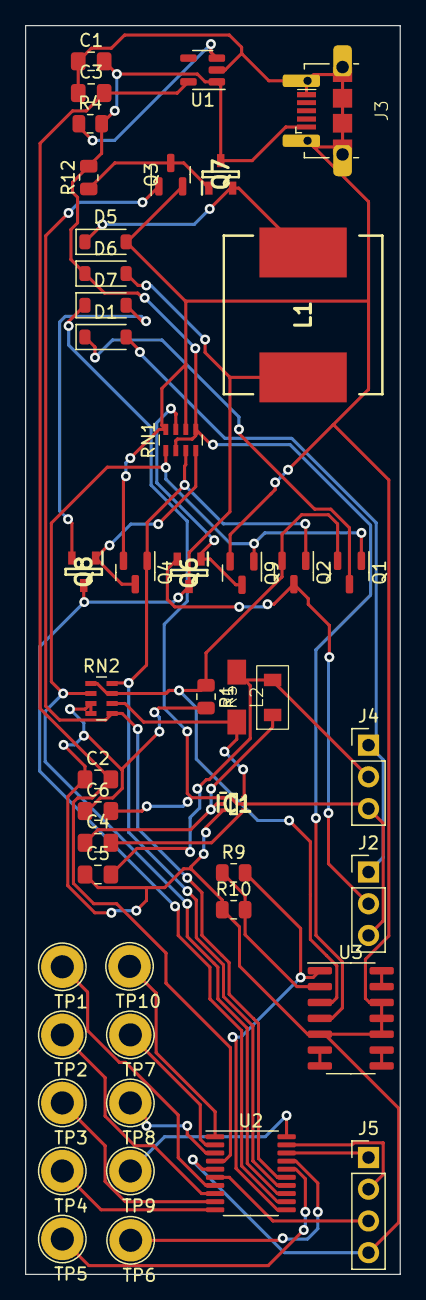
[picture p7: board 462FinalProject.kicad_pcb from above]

Board: 2 copper layers, 30.0 x 100.0 mm, 46 parts (0 on the bottom side), 40 nets.

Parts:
C1, C2, C3, C5, C6: 10u; C_0805_2012Metric_Pad1.18x1.45mm_HandSolder
C4: .1u; C_0805_2012Metric_Pad1.18x1.45mm_HandSolder
D1, D5, D6, D7: MBR0530; D_SOD-123
IC1: TPS562231DRLR; SOTFL50P160X60-6N
J2: 3_Pin_Header_to_Battery; PinHeader_1x03_P2.54mm_Vertical
J3: USB_B_Micro; USB_Micro-B_roundholes
J4: 3_Pin_Header_to_IPOD; PinHeader_1x03_P2.54mm_Vertical
J5: Conn_01x04_Pin; PinHeader_1x04_P2.54mm_Vertical
L1: SRR1205-500YL; SRR1205500YL
L2: 3.3u; CC322522A-4R7K
Q1, Q2: MMFTN6001; SOT-23
Q3, Q4, Q9: SI2302; SOT-23
Q6, Q7, Q8: BSS84AK,215; SOT95P230X110-3N
R1: 100m; R_0805_2012Metric
R4, R10, R12: 1k; R_0805_2012Metric
R5: 45.3k; CR0603-FX-4532ELF
R9: 100k; R_0805_2012Metric
RN1, RN2: R_Pack04_Split_2; R_Array_Concave_4x0603
TP1, TP2, TP3, TP4, TP5, TP6, TP7, TP8, TP9, TP10: TestPoint; TestPoint_Loop_D2.50mm_Drill1.85mm
U1: MIC5504-3.3YM5; SOT-23-5
U2: STM32G030F6Px; TSSOP-20_4.4x6.5mm_P0.65mm
U3: SOIC-14_3.9x8.7mm_P1.27mm

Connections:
3.3v Battery: C5.2, J4.2, L2.2, R5.1
ADC_Current: R9.2, U2.11 (PA4), U3.1 (OUTA)
ADC_v-to-c: Q1.2 (S), Q2.2 (S), R1.1, RN2.1 (R1.1), RN2.7 (R2.2), U3.3 (INA+)
BST: C4.2, IC1.4 (BST)
FB: IC1.6 (FB), R5.2, RN2.6 (R3.2)
GND: C1.1, C2.1, C3.1, C5.1, C6.1, D5.2 (A), IC1.3 (GND), J3.5 (GND), J3.6 (Shield), J5.4, Q3.2 (S), Q4.2 (S), Q9.2 (S), R1.2, R10.1, RN1.6 (R3.2), RN1.8 (R1.2), RN2.3 (R3.1), RN2.4 (R4.1), U1.2 (GND), U2.5 (VSS), U3.5 (INB+), U3.10 (INC+), U3.11 (VSS), U3.12 (IND+)
LiPO1_Control: Q1.1 (G), Q9.1 (G), RN1.1 (R1.1), RN2.2 (R2.1), U2.13 (PA6)
LiPO2_Control: Q2.1 (G), Q4.1 (G), RN1.3 (R3.1), RN2.8 (R1.2), U2.14 (PA7)
LiPO High: C6.2, D7.1 (K), IC1.1 (VIN), IC1.5 (EN), J2.3, J4.3
LiPO Low: D1.2 (A), J2.1, J4.1
LiPO Mid: J2.2, Q2.3 (D), Q6.2 (S)
MCU Vdd: C2.2, C3.2, U1.5 (VOUT), U2.4 (VDD)
NRST: J5.3, U2.6 (NRST)
unnamed: D1.1 (K), Q1.3 (D)
unnamed: D5.1 (K), L1.1, Q7.2 (S)
unnamed: D7.2 (A), Q8.2 (S)
unnamed: Q3.3 (D), Q7.1 (G), R12.1
unnamed: Q4.3 (D), Q8.1 (G), RN1.4 (R4.1)
unnamed: Q6.1 (G), Q9.3 (D), RN1.7 (R2.2)
unnamed: R4.1, U1.3 (EN)
unnamed: R9.1, R10.2, U3.2 (INA-)
unnamed: U3.6 (INB-), U3.7 (OUTB)
unnamed: U3.8 (OUTA), U3.9 (INC-)
unnamed: U3.13 (IND-), U3.14 (OUTD)
PA0_MCU: TP1.1, U2.7 (PA0)
PA1_MCU: TP2.1, U2.8 (PA1)
PA2_MCU: TP3.1, U2.9 (PA2)
PA3_MCU: TP4.1, U2.10 (PA3)
PA11_PA9_MCU: TP5.1, U2.16 (PA11/PA9)
PA12_PA10_MCU: TP6.1, U2.17 (PA12/PA10)
PB3_PB4_PB5P_PB6_MCU: TP9.1, U2.20 (PB3/PB4/PB5/PB6)
PB7_PB8_MCU: TP10.1, U2.1 (PB7/PB8)
PC14_PB9_MCU: TP7.1, U2.2 (PC14/PB9)
PC15_MCU: TP8.1, U2.3 (PC15)
SW: C4.1, IC1.2 (SW), L2.1
SWCLK: J5.2, U2.19 (PA14/PA15)
SWDIO: J5.1, U2.18 (PA13)
Switch_Regulated_V: D6.2 (A), L1.2, Q6.3 (D), Q8.3 (D), U2.12 (PA5)
Switch_Regulator_PWM: Q3.1 (G), RN2.5 (R4.2), U2.15 (PB0/PB1/PB2/PA8)
USB Vdc: C1.2, D6.1 (K), J3.1 (VBUS), Q7.3 (D), R4.2, R12.2, RN1.2 (R2.1), RN1.5 (R4.2), U1.1 (VIN), U3.4 (VDD)

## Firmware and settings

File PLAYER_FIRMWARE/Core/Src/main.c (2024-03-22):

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
/* Includes ------------------------------------------------------------------*/
#include "main.h"
#include "cmsis_os.h"
#include "app_fatfs.h"

/* USER CODE BEGIN Includes */
#include <string.h>
#include <stdbool.h>

#include <FreeRTOS.h>
#include <task.h>

#include "stm32g4xx_hal.h"

#include "console.h"
#include "buttons.h"
/* USER CODE END Includes */

typedef StaticTask_t osStaticThreadDef_t;
ADC_HandleTypeDef hadc1;
ADC_HandleTypeDef hadc2;
ADC_HandleTypeDef hadc3;
ADC_HandleTypeDef hadc4;
ADC_HandleTypeDef hadc5;

DAC_HandleTypeDef hdac1;
DAC_HandleTypeDef hdac3;
DAC_HandleTypeDef hdac4;
DMA_HandleTypeDef hdma_dac1_ch1;
DMA_HandleTypeDef hdma_dac1_ch2;

OPAMP_HandleTypeDef hopamp1;
OPAMP_HandleTypeDef hopamp3;
OPAMP_HandleTypeDef hopamp4;
OPAMP_HandleTypeDef hopamp6;

QSPI_HandleTypeDef hqspi1;

SPI_HandleTypeDef hspi2;
SPI_HandleTypeDef hspi3;
SPI_HandleTypeDef hspi4;

TIM_HandleTypeDef htim2;
TIM_HandleTypeDef htim6;

UART_HandleTypeDef huart5;
USART_HandleTypeDef husart3;
DMA_HandleTypeDef hdma_uart5_tx;

/* Definitions for defaultTask */
osThreadId_t defaultTaskHandle;
uint32_t defaultTaskBuffer[ 512 ];
osStaticThreadDef_t defaultTaskControlBlock;
const osThreadAttr_t defaultTask_attributes = {
  .name = "defaultTask",
  .stack_mem = &defaultTaskBuffer[0],
  .stack_size = sizeof(defaultTaskBuffer),
  .cb_mem = &defaultTaskControlBlock,
  .cb_size = sizeof(defaultTaskControlBlock),
  .priority = (osPriority_t) osPriorityNormal,
};
/* USER CODE BEGIN PV */
	int counter;
	bool freeRTOS_ready = false;
/* USER CODE END PV */

void SystemClock_Config(void);
static void MX_GPIO_Init(void);
static void MX_DMA_Init(void);
static void MX_DAC1_Init(void);
static void MX_DAC3_Init(void);
static void MX_DAC4_Init(void);
static void MX_OPAMP1_Init(void);
static void MX_OPAMP3_Init(void);
static void MX_OPAMP4_Init(void);
static void MX_OPAMP6_Init(void);
static void MX_QUADSPI1_Init(void);
static void MX_SPI2_Init(void);
static void MX_SPI3_Init(void);
static void MX_SPI4_Init(void);
static void MX_UART5_Init(void);
static void MX_USART3_Init(void);
static void MX_ADC1_Init(void);
static void MX_ADC2_Init(void);
static void MX_ADC3_Init(void);
static void MX_ADC4_Init(void);
static void MX_ADC5_Init(void);
static void MX_TIM6_Init(void);
static void MX_TIM2_Init(void);
void StartDefaultTask(void *argument);

/* USER CODE BEGIN 0 */
#include "jeremy.h"
#include "wyatt.h"
#include "bryant.h"
#include "braeden.h"
#include "console.h"

uint8_t __attribute__((section(".sram2"))) wyatt_memspace[4096];
uint8_t __attribute__((section(".sram2"))) bryant_memspace[4096];
uint8_t __attribute__((section(".sram2"))) braeden_memspace[4096];
uint8_t __attribute__((section(".sram2"))) jeremy_memspace[4096];
uint8_t __attribute__((section(".ccm_sram_all"))) console_memspace[2048];

uint8_t __attribute__((section(".sram1_upper"))) audio_buffer[AUD_BUFFER_SIZE]; //48k

/* USER CODE END 0 */

/**
  * @brief  The application entry point.
  * @retval int
  */
int main(void)
{
  /* MCU Configuration--------------------------------------------------------*/

  /* Reset of all peripherals, Initializes the Flash interface and the Systick. */
  HAL_Init();

  /* Configure the system clock */
  SystemClock_Config();

  /* Initialize all configured peripherals */
  MX_GPIO_Init();
  MX_DMA_Init();
  MX_DAC1_Init();
  MX_DAC3_Init();
  MX_DAC4_Init();
  MX_OPAMP1_Init();
  MX_OPAMP3_Init();
  MX_OPAMP4_Init();
  MX_OPAMP6_Init();
  MX_QUADSPI1_Init();
  MX_SPI2_Init();
  MX_SPI3_Init();
  MX_SPI4_Init();
  MX_UART5_Init();
  MX_USART3_Init();
  MX_ADC1_Init();
  MX_ADC2_Init();
  MX_ADC3_Init();
  MX_ADC4_Init();
  MX_ADC5_Init();
  if (MX_FATFS_Init() != APP_OK) {
    Error_Handler();
  }
  MX_TIM6_Init();
  MX_TIM2_Init();
  /* USER CODE BEGIN 2 */
  empty_console_memory();
  HAL_TIM_Base_Start_IT(&htim2);
  {
	  HAL_UART_Transmit(&CONSOLE_UART_HANDLE, "\n\n-------------------------------\n" , 33, 0xFFFF);
	  const char tmp[] = "----Peripherals Initialized----\n";
	  const char tmp2[] = "\n----SYSTEM RESET---------------\n";
	  HAL_UART_Transmit(&CONSOLE_UART_HANDLE, tmp2, sizeof(tmp2) , 0xFFFF);
	  HAL_UART_Transmit(&CONSOLE_UART_HANDLE, tmp, sizeof(tmp) , 0xFFFF);
	  HAL_UART_Transmit(&CONSOLE_UART_HANDLE, "Build: " , 7, 0xFFFF);
	  HAL_UART_Transmit(&CONSOLE_UART_HANDLE, __DATE__, sizeof(__DATE__) , 0xFFFF);
	  HAL_UART_Transmit(&CONSOLE_UART_HANDLE, " " , 1, 0xFFFF);
	  HAL_UART_Transmit(&CONSOLE_UART_HANDLE, __TIME__, sizeof(__TIME__) , 0xFFFF);
	  HAL_UART_Transmit(&CONSOLE_UART_HANDLE, "\n" , 1, 0xFFFF);
	  HAL_UART_Transmit(&CONSOLE_UART_HANDLE, "-------------------------------\n" , 32, 0xFFFF);
  }
  freeRTOS_ready = true;
  HAL_TIM_Base_Start_IT(&AUDIO_44_1_KHZ_TIMER);
  /* USER CODE END 2 */

  /* Init scheduler */
  osKernelInitialize();

  /* USER CODE BEGIN RTOS_MUTEX */
  /* add mutexes, ... */
  /* USER CODE END RTOS_MUTEX */

  /* USER CODE BEGIN RTOS_SEMAPHORES */
  /* add semaphores, ... */
  /* USER CODE END RTOS_SEMAPHORES */

  /* USER CODE BEGIN RTOS_TIMERS */
  /* start timers, add new ones, ... */
  /* USER CODE END RTOS_TIMERS */

  /* USER CODE BEGIN RTOS_QUEUES */
  /* add queues, ... */
  /* USER CODE END RTOS_QUEUES */

  /* Create the thread(s) */
  /* creation of defaultTask */
  defaultTaskHandle = osThreadNew(StartDefaultTask, NULL, &defaultTask_attributes);

  /* USER CODE BEGIN RTOS_THREADS */
  static StaticTask_t threads[5];
  xTaskCreateStatic(console_main, 	"console_main_thread", 	512, NULL, 5, (StackType_t *)console_memspace, 	&threads[4]);
  xTaskCreateStatic(wyatt_main, 	"wyatt_main_thread", 	1024, NULL, 5, (StackType_t *)wyatt_memspace, 	&threads[0]);
  xTaskCreateStatic(jeremy_main, 	"jeremy_main_thread", 	1024, NULL, 5, (StackType_t *)jeremy_memspace, 	&threads[1]);
  xTaskCreateStatic(bryant_main, 	"bryant_main_thread", 	1024, NULL, 5, (StackType_t *)bryant_memspace, 	&threads[2]);
  xTaskCreateStatic(braeden_main, 	"braeden_main_thread", 	1024, NULL, 5, (StackType_t *)braeden_memspace, &threads[3]);

  /* USER CODE END RTOS_THREADS */

  /* USER CODE BEGIN RTOS_EVENTS */
  /* add events, ... */
  /* USER CODE END RTOS_EVENTS */

  /* Start scheduler */
  osKernelStart();
  /* We should never get here as control is now taken by the scheduler */
  /* Infinite loop */
  /* USER CODE BEGIN WHILE */
  while (1)
  {
    /* USER CODE END WHILE */

    /* USER CODE BEGIN 3 */
  }
  /* USER CODE END 3 */
}

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
/* USER CODE BEGIN Header_StartDefaultTask */
/**
  * @brief  Function implementing the defaultTask thread.
  * @param  argument: Not used
  * @retval None
  */
/* USER CODE END Header_StartDefaultTask */
void StartDefaultTask(void *argument)
{
  /* USER CODE BEGIN 5 */
	while(1){
		vTaskDelay(5000);
		console_print_time(), console_write("System Up\n", 11);
	}
  /* USER CODE END 5 */
}

/**
  * @brief  Period elapsed callback in non blocking mode
  * @note   This function is called  when TIM7 interrupt took place, inside
  * HAL_TIM_IRQHandler(). It makes a direct call to HAL_IncTick() to increment
  * a global variable "uwTick" used as application time base.
  * @param  htim : TIM handle
  * @retval None
  */
void HAL_TIM_PeriodElapsedCallback(TIM_HandleTypeDef *htim)
{
  /* USER CODE BEGIN Callback 0 */
	  if(htim->Instance == TIM2)
	  {
		  if (HAL_GPIO_ReadPin(GPIOC, GPIO_PIN_2) == GPIO_PIN_RESET)
		  {
		   if (HAL_GPIO_ReadPin(GPIOC, GPIO_PIN_4) == GPIO_PIN_RESET)
		   {
		    while (HAL_GPIO_ReadPin(GPIOC, GPIO_PIN_4) == GPIO_PIN_RESET){};
		    counter--;
		    up_pressed = true;
		    while (HAL_GPIO_ReadPin(GPIOC, GPIO_PIN_2) == GPIO_PIN_RESET){};
		   }
		  }

		   else {
			   if (HAL_GPIO_ReadPin(GPIOC, GPIO_PIN_4) == GPIO_PIN_RESET)
			   	  {
		    counter++;
		    down_pressed = true;
		    while (HAL_GPIO_ReadPin(GPIOC, GPIO_PIN_4) == GPIO_PIN_RESET){};
		    while (HAL_GPIO_ReadPin(GPIOC, GPIO_PIN_2) == GPIO_PIN_RESET){};
			   	  }
		   }
	  }

	  if(htim->Instance == AUDIO_44_1_KHZ_TIMER.Instance) {
		  get_audio_sample();
	  }
  /* USER CODE END Callback 0 */
  if (htim->Instance == TIM7) {
    HAL_IncTick();
  }
}

/**
  * @brief  This function is executed in case of error occurrence.
  * @retval None
  */
void Error_Handler(void)
{
  /* USER CODE BEGIN Error_Handler_Debug */
  /* User can add his own implementation to report the HAL error return state */
  __disable_irq();
  while (1)
  {
  }
  /* USER CODE END Error_Handler_Debug */
}

#ifdef  USE_FULL_ASSERT
/**
  * @brief  Reports the name of the source file and the source line number
  *         where the assert_param error has occurred.
  * @param  file: pointer to the source file name
  * @param  line: assert_param error line source number
  * @retval None
  */
void assert_failed(uint8_t *file, uint32_t line)
{
  /* USER CODE BEGIN 6 */
  /* User can add his own implementation to report the file name and line number,
     ex: printf("Wrong parameters value: file %s on line %d\r\n", file, line) */
  /* USER CODE END 6 */
}
#endif /* USE_FULL_ASSERT */

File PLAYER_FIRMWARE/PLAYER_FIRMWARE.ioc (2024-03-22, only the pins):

Mcu.UserName=STM32G474VEHx
PA0.GPIO_Label=TFT_SPI_DC
PA0.Signal=GPIO_Output
PA1.GPIO_Label=AUD_GRN_MIC_POSTAMP
PA1.Signal=ADC1_IN2
PA10.GPIO_Label=DOWN_BUTTON
PA10.Signal=GPXTI10
PA11.GPIO_Label=UP_BUTTON
PA11.Signal=GPXTI11
PA12.GPIO_Label=RIGHT_BUTTON
PA12.Signal=GPXTI12
PA13.Signal=SYS_JTMS-SWDIO
PA14.Signal=SYS_JTCK-SWCLK
PA15.Signal=SYS_JTDI
PA2.GPIO_Label=AUD_ORANGE_L_PREAMP_AUDIO
PA2.Signal=OPAMP1_VOUT
PA4.GPIO_Label=AUD_GREEN_L_PREAMP_AUDIO
PA4.Signal=COMP_DAC11_group
PA5.GPIO_Label=AUD_GREEN_R_PREAMP_AUDIO
PA5.Signal=COMP_DAC12_group
PA6.GPIO_Label=TFT_LED_LEVEL
PA6.Signal=GPIO_Output
PA7.GPIO_Label=PINK_BUFFERED_ANALOG_IN_S
PA7.Signal=ADC2_IN4
PA8.GPIO_Label=LEFT_BUTTON
PA8.Signal=GPXTI8
PA9.GPIO_Label=AUD_ORANGE_S_UNBUFFERED_IN
PA9.Signal=ADC5_IN2
PB1.GPIO_Label=AUD_ORANGE_PREAMP_AUDIO
PB1.Signal=OPAMP3_VOUT
PB11.Signal=OPAMP6_VOUT
PB12.Signal=OPAMP4_VOUT
PB13.Signal=SPI2_SCK
PB14.Signal=SPI2_MISO
PB15.Signal=SPI2_MOSI
PB3.Signal=SYS_JTDO-SWO
PB4.Signal=SYS_JTRST
PB5.Signal=SPI3_MOSI
PB6.GPIO_Label=TFT_NRST
PB6.Signal=GPIO_Output
PB9.Signal=USART3_TX
PC0.GPIO_Label=AUD_GREEN_L_OUTPUT_EN
PC0.Signal=GPIO_Output
PC1.GPIO_Label=AUD_GREEN_R_OUTPUT_EN
PC1.Signal=GPIO_Output
PC10.Signal=SPI3_SCK
PC11.Signal=SPI3_MISO
PC12.Signal=UART5_TX
PC14-OSC32_IN.Signal=RCC_OSC32_IN
PC15-OSC32_OUT.Signal=RCC_OSC32_OUT
PC2.GPIO_Label=ROT_A
PC2.Signal=GPIO_Input
PC3.GPIO_Label=ROT_B
PC3.Signal=GPIO_Output
PC4.GPIO_Label=ROT_C
PC4.Signal=GPIO_Input
PC5.GPIO_Label=ROT_S1
PC5.Signal=GPXTI5
PC6.GPIO_Label=ROT_S2
PC6.Signal=GPIO_Output
PC9.GPIO_Label=MICRO_SD_CS
PC9.Signal=GPIO_Output
PD1.GPIO_Label=BRIDGE_CLK
PD1.Signal=S_TIM8_CH4
PD10.Signal=USART3_CK
PD11.GPIO_Label=PINK_BUFFERED_ANALOG_IN_R1
PD11.Signal=ADC3_IN8
PD12.GPIO_Label=PINK_BUFFERED_ANALOG_IN_T
PD12.Signal=ADC4_IN9
PD13.GPIO_Label=AUD_BLACK_R1_UNBUFFERED_IN
PD13.Signal=ADC5_IN10
PD14.GPIO_Label=AUD_BLACK_T_UNBUFFERED_IN
PD14.Signal=ADC5_IN11
PD15.GPIO_Label=TFT_SPI_NSS
PD15.Signal=SPI2_NSS
PD2.Signal=UART5_RX
PD3.Signal=QUADSPI1_BK2_NCS
PD4.Signal=QUADSPI1_BK2_IO0
PD5.Signal=QUADSPI1_BK2_IO1
PD6.Signal=QUADSPI1_BK2_IO2
PD7.Signal=QUADSPI1_BK2_IO3
PD8.GPIO_Label=VOLUME_ANALOG_IN
PD8.Signal=ADC5_IN12
PD9.Signal=USART3_RX
PE11.Signal=QUADSPI1_BK1_NCS
PE12.Signal=QUADSPI1_BK1_IO0
PE13.Signal=QUADSPI1_BK1_IO1
PE14.Signal=QUADSPI1_BK1_IO2
PE15.Signal=QUADSPI1_BK1_IO3
PE2.Signal=SPI4_SCK
PE4.GPIO_Label=SD_CS
PE4.Signal=GPIO_Output
PE5.Signal=SPI4_MISO
PE6.Signal=SPI4_MOSI
PE8.GPIO_Label=AUD_BLACK_S_UNBUFFERED_IN
PE8.Signal=ADC5_IN6
PF0-OSC_IN.Signal=RCC_OSC_IN
PF1-OSC_OUT.Signal=RCC_OSC_OUT
PF10.Signal=QUADSPI1_CLK
PF2.GPIO_Label=AUD_ORANGE_L_OUTPUT_EN
PF2.Signal=GPIO_Output
PF9.GPIO_Label=AUD_ORANGE_R_OUTPUT_EN
PF9.Signal=GPIO_Output

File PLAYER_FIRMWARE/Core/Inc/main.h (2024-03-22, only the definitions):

#define SD_SPI_HANDLE hspi4
#define SD_CS_GPIO_Port GPIOE
#define SD_CS_Pin GPIO_PIN_4
#define AUD_GREEN_DAC hdac1
#define AUDIO_44_1_KHZ_TIMER htim6
#define AUD_BUFFER_SIZE 49152
#define CONSOLE_UART_HANDLE huart5
#define SD_CS_Pin GPIO_PIN_4
#define SD_CS_GPIO_Port GPIOE
#define TFT_NRST_Pin GPIO_PIN_6
#define TFT_NRST_GPIO_Port GPIOB
#define BRIDGE_CLK_Pin GPIO_PIN_1
#define BRIDGE_CLK_GPIO_Port GPIOD
#define RIGHT_BUTTON_Pin GPIO_PIN_12
#define RIGHT_BUTTON_GPIO_Port GPIOA
#define RIGHT_BUTTON_EXTI_IRQn EXTI15_10_IRQn
#define UP_BUTTON_Pin GPIO_PIN_11
#define UP_BUTTON_GPIO_Port GPIOA
#define UP_BUTTON_EXTI_IRQn EXTI15_10_IRQn
#define DOWN_BUTTON_Pin GPIO_PIN_10
#define DOWN_BUTTON_GPIO_Port GPIOA
#define DOWN_BUTTON_EXTI_IRQn EXTI15_10_IRQn
#define AUD_ORANGE_S_UNBUFFERED_IN_Pin GPIO_PIN_9
#define AUD_ORANGE_S_UNBUFFERED_IN_GPIO_Port GPIOA
#define AUD_ORANGE_R_OUTPUT_EN_Pin GPIO_PIN_9
#define AUD_ORANGE_R_OUTPUT_EN_GPIO_Port GPIOF
#define MICRO_SD_CS_Pin GPIO_PIN_9
#define MICRO_SD_CS_GPIO_Port GPIOC
#define LEFT_BUTTON_Pin GPIO_PIN_8
#define LEFT_BUTTON_GPIO_Port GPIOA
#define LEFT_BUTTON_EXTI_IRQn EXTI9_5_IRQn
#define ROT_A_Pin GPIO_PIN_2
#define ROT_A_GPIO_Port GPIOC
#define AUD_GREEN_L_OUTPUT_EN_Pin GPIO_PIN_0
#define AUD_GREEN_L_OUTPUT_EN_GPIO_Port GPIOC
#define AUD_GREEN_R_OUTPUT_EN_Pin GPIO_PIN_1
#define AUD_GREEN_R_OUTPUT_EN_GPIO_Port GPIOC
#define AUD_BLACK_T_UNBUFFERED_IN_Pin GPIO_PIN_14
#define AUD_BLACK_T_UNBUFFERED_IN_GPIO_Port GPIOD
#define ROT_S2_Pin GPIO_PIN_6
#define ROT_S2_GPIO_Port GPIOC
#define ROT_B_Pin GPIO_PIN_3
#define ROT_B_GPIO_Port GPIOC
#define AUD_GRN_MIC_POSTAMP_Pin GPIO_PIN_1
#define AUD_GRN_MIC_POSTAMP_GPIO_Port GPIOA
#define AUD_ORANGE_L_OUTPUT_EN_Pin GPIO_PIN_2
#define AUD_ORANGE_L_OUTPUT_EN_GPIO_Port GPIOF
#define TFT_SPI_DC_Pin GPIO_PIN_0
#define TFT_SPI_DC_GPIO_Port GPIOA
#define AUD_BLACK_R1_UNBUFFERED_IN_Pin GPIO_PIN_13
#define AUD_BLACK_R1_UNBUFFERED_IN_GPIO_Port GPIOD
#define TFT_SPI_NSS_Pin GPIO_PIN_15
#define TFT_SPI_NSS_GPIO_Port GPIOD
#define AUD_ORANGE_L_PREAMP_AUDIO_Pin GPIO_PIN_2
#define AUD_ORANGE_L_PREAMP_AUDIO_GPIO_Port GPIOA
#define AUD_GREEN_L_PREAMP_AUDIO_Pin GPIO_PIN_4
#define AUD_GREEN_L_PREAMP_AUDIO_GPIO_Port GPIOA
#define AUD_BLACK_S_UNBUFFERED_IN_Pin GPIO_PIN_8
#define AUD_BLACK_S_UNBUFFERED_IN_GPIO_Port GPIOE
#define PINK_BUFFERED_ANALOG_IN_R1_Pin GPIO_PIN_11
#define PINK_BUFFERED_ANALOG_IN_R1_GPIO_Port GPIOD
#define AUD_GREEN_R_PREAMP_AUDIO_Pin GPIO_PIN_5
#define AUD_GREEN_R_PREAMP_AUDIO_GPIO_Port GPIOA
#define TFT_LED_LEVEL_Pin GPIO_PIN_6
#define TFT_LED_LEVEL_GPIO_Port GPIOA
#define ROT_S1_Pin GPIO_PIN_5
#define ROT_S1_GPIO_Port GPIOC
#define ROT_S1_EXTI_IRQn EXTI9_5_IRQn
#define PINK_BUFFERED_ANALOG_IN_T_Pin GPIO_PIN_12
#define PINK_BUFFERED_ANALOG_IN_T_GPIO_Port GPIOD
#define PINK_BUFFERED_ANALOG_IN_S_Pin GPIO_PIN_7
#define PINK_BUFFERED_ANALOG_IN_S_GPIO_Port GPIOA
#define ROT_C_Pin GPIO_PIN_4
#define ROT_C_GPIO_Port GPIOC
#define AUD_ORANGE_PREAMP_AUDIO_Pin GPIO_PIN_1
#define AUD_ORANGE_PREAMP_AUDIO_GPIO_Port GPIOB
#define VOLUME_ANALOG_IN_Pin GPIO_PIN_8
#define VOLUME_ANALOG_IN_GPIO_Port GPIOD

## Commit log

2024-03-06 Initial Copy In
    [AUD_OUTPUT_AMP.kicad_sch, mic_aud_conditioning_grn.kicad_sch, player_system.kicad_pcb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]
2024-03-06 Updated footprints fixes several bad footprints. Not all footprints are fixed
    [462FinalProject.kicad_sch]
2024-03-06 "Complete" kicad pcb
    [462FinalProject.kicad_pcb]
2024-03-06 Nearly done with player PCB
    [AUD_OUTPUT_AMP.kicad_sch, mic_aud_conditioning_grn.kicad_sch, player_system.kicad_pcb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]
2024-03-07 Fab Adjustments
    [player_system-B_Cu.gbl, player_system-B_Mask.gbs, player_system-B_Paste.gbp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]
2024-03-07 PCBs Done
    [462FinalProject-B_Cu.gbl, 462FinalProject-B_Mask.gbs, 462FinalProject-B_Paste.gbp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]
2024-03-13 Freertos Config Start
    [player_system.csv]
2024-03-14 Getting DAC DMA set up
    [player_system.kicad_sch]
2024-03-14 Configure DMA
2024-03-14 FreeRTOS Hang fix - Stub for wyatt's main was incomplete.
    [main.c]
2024-03-14 Testing UART VCP
2024-03-15 Bringup for PCB
2024-03-15 Adding rotary encoder code
2024-03-15 Realized i pushed broken code...
    [bryant.c, main.c]
2024-03-15 Updated .gitignore to ignore kicad locks
2024-03-15 Fix PCB Mistake: Crystal Oscilator has two GND pins, not shared pins
    [player_system.kicad_sch]
2024-03-15 PCB update
    [462FinalProject.csv]
2024-03-15 put #include "stm32g4xx_hal.h" where #include "stm32f4xx_hal.h" used to be in FATFS and ili9341 files
2024-03-17 Ignore backup files in kicad
2024-03-17 Remove automatic KiCad Backups
2024-03-17 Wrote a program for setting the baud rate on linux to an arbitrary value -> Got the debug UART VCP running at the full 16Mbaud.
2024-03-18 Added build time message, console printing utilities.
2024-03-18 Use DMA for console printer
2024-03-19 Tweaked console printing utility. Hopefully fixed SD card.
    [PLAYER_FIRMWARE.ioc, console.c, jeremy.c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]
2024-03-19 Create buttons files
2024-03-20 Button code, Add braeden hook for audio
2024-03-20 Change quotes for <..> on include in buttons.h
2024-03-20 Remove button testing code frm my main
2024-03-20 implemented buttons w/ file select
2024-03-20 Connecting up ROT encoder
2024-03-20 synced buttons to display
2024-03-21 adc v1
2024-03-22 Push current state of the union
2024-03-22 Enable tim6 update interrupt
2024-03-22 Testing code for ADC
2024-03-22 Faster ADC samples
2024-03-22 Revert "fixed some mistakes"
    This reverts commit ab09db9248b5b7c896f5085404e4330690ecd1ca.
    [braeden.c]
2024-03-22 Restore ADC code
2024-03-22 Timer freq fix

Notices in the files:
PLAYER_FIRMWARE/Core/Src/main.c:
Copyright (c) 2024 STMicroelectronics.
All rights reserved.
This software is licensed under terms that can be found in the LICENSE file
